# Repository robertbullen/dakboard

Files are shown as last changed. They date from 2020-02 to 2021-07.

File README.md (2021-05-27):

# dakboard

This project starts with a [DIY DAKboard](https://blog.dakboard.com/diy-wall-display/) and customizes it with two features:

- A [Python package](interdaktive/) that interfaces with a PIR motion sensor to programmatically turn the display on and off.
- [Handwritten CSS](css/) for a two-column portrait layout that looks like this:

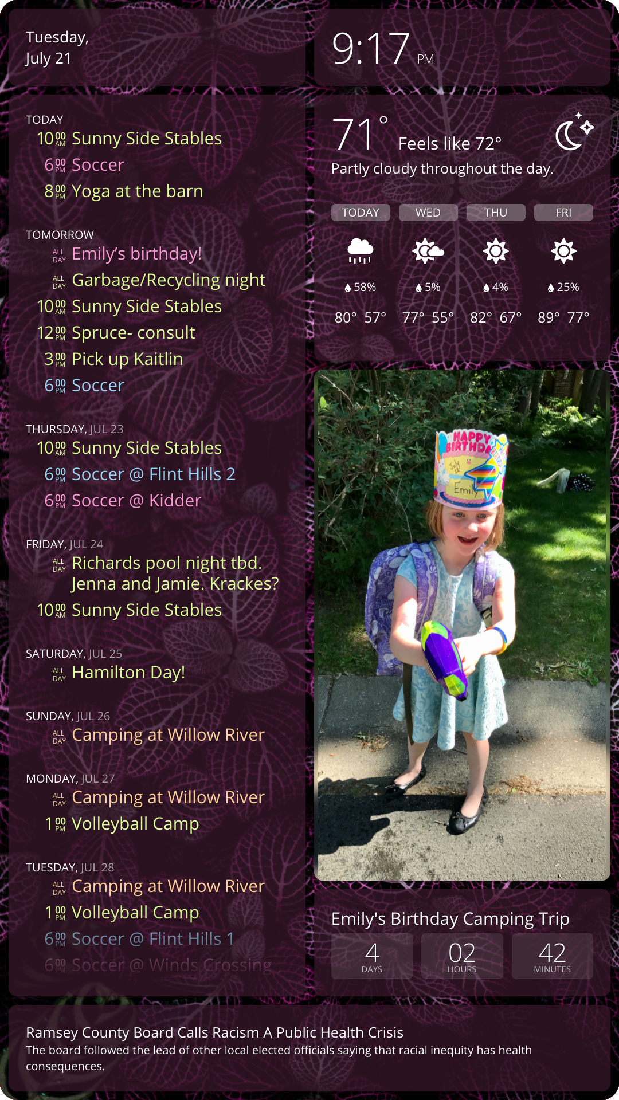
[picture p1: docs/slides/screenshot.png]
    

    _[Background photo](https://unsplash.com/photos/gE1phX0Lbos) by [Hybrid](https://unsplash.com/@artbyhybrid?utm_medium=referral&utm_campaign=photographer-credit&utm_content=creditBadge) on [Unsplash](https://unsplash.com)._

## Presentation

I created an [online presentation](https://robertbullen.github.io/dakboard/) about this project for a talk at work:

- It's a [Reveal.js](https://revealjs.com/#/) project and its source code can be found in this repo's [docs/](docs/) subdirectory. My slides, in particular, are found in [docs/slides/](docs/slides/).
- A viewable instance is hosted by [GitHub Pages](https://pages.github.com/) at <https://robertbullen.github.io/dakboard/>.

## Credits

This project was sponsored in part by my employer, [Constellation](https://constellationmutual.com/). As part of its employee growth and development strategy, Constellation allocates IT staff 12 Personal Hack Days per year to pursue self-guided technology-related interests. I used four of my Personal Hack Days (plus more of my own time) working on this project.

## Software

### Raspberry Pi Configuration

1. Follow the steps found at [DIY Wall Display](https://blog.dakboard.com/diy-wall-display/) until the "Turn the monitor on and off automatically (optional)" section. Rather than control the display on a schedule, as that section explains, this project controls it via a motion sensor.

2. Depending on the display being used, install the HDMI-CEC client. Screenly has a great [article on three ways to turn on/off a monitor](https://www.screenly.io/blog/2017/07/02/how-to-automatically-turn-off-and-on-your-monitor-from-your-raspberry-pi/) programmatically from a Raspberry Pi. That article is two and a half years old at the time of this writing and the installation command is slightly different now:

    ```bash
    sudo apt-get install cec-utils
    ```

    Another great tutorial is [Using HDMI-CEC on a Raspberry Pi](https://pimylifeup.com/raspberrypi-hdmi-cec/).

    With that information in hand, some trial and error lead me to the most effective command for each of the displays that I tested, which I documented in my [presentation](https://robertbullen.github.io/dakboard/#/software-controlling-displays). Your mileage may vary and you may or may not need the CEC client.

3. [_Optional_] Add and configure a USB 3.0-attached SSD drive as the boot drive for a larger swapfile with more reliable I/O.

    > Background:
    >
    > I never needed to configure additional swap space on the Pi 3 that I used for prototyping. But when using the Pi 4 for a matter of hours or days, the system would eventually encounter an out-of-memory scenario that manifested as a Chromium "Aww, Snap!" error. Perhaps I never ran the Pi 3 for long enough to observe the error. Or maybe running the Pi 4 at 1440p (instead of 1080p) is demanding enough to warrant additional memory. In retrospect I wish I would've opted for the 2GB or 4Gb version of the Pi 4 and avoided this issue altogether.
    >
    > Raspbian ships with a preconfigured 100MB swap file at `/var/swap`, which by default resides on the SD card. Simply increasing the size of that swap file prevented the out-of-memory errors. However, there are many warnings online advising against using the SD card for swapping because it isn't made for a lot of random I/O and can eventually become corrupted, taking the OS with it. I can confirm that with my own experiences using cheap SD cards.
    >
    > In an effort to heed those warnings, I first tried using [ZRAM](https://github.com/novaspirit/rpi_zram). This approach lengthened the amount of time between "Aww, Snap!" occurrences, but didn't eliminate them.
    >
    > I eventually settled on using a spare SSD to use as the boot drive, with benefits of faster and more reliable I/O.

    1. Configure the system to boot from an external SSD: <https://www.tomshardware.com/how-to/boot-raspberry-pi-4-usb>.
    2. Increase the swapfile size according to the instructions at <https://nebl.io/neblio-university/enabling-increasing-raspberry-pi-swap/>. In my case, I changed the following lines:

        ```bash
        #CONF_SWAPSIZE=100
        ```

        ```bash
        CONF_SWAPFACTOR=2
        ```

4. Clone this repository to your Raspberry Pi.

    ```bash
    # Substitute your forked repository URL if necessary.
    git clone https://github.com/robertbullen/dakboard.git
    ```

5. Modify `start.sh` script's `start_detector()` function to use desired parameters. For example, you may want to change `--display-type=video-core` to `--display-type=cec` if a TV will be used for the display.

6. Start the Python motion detector on boot by adding these lines to /etc/rc.local:

    ```bash
    # This assumes the user is the default (pi) and that the repository has
    # been cloned to that user's home directory.
    pushd /home/pi/dakboard || exit $?
    sudo ./update.sh || exit $?
    sudo ./start.sh &
    popd
    ```

7. Configure the system to wait for the network at boot:

    Both Chrome and the Python motion detector are started ASAP, and they both require network access to function properly. Do the following to ensure they succeed:

    ```bash
    sudo raspi-config
    ```

    At the time of this writing, the menu choices to make are:

    1. `1 System Options`
    2. `S6 Network at Boot`
    3. `<Yes>`

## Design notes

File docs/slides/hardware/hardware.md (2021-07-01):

<!-- .slide: id="hardware-hardware" -->
# Hardware

===
<!-- .slide: class="columns layout" id="hardware-prototype" -->
## Prototype

- Column

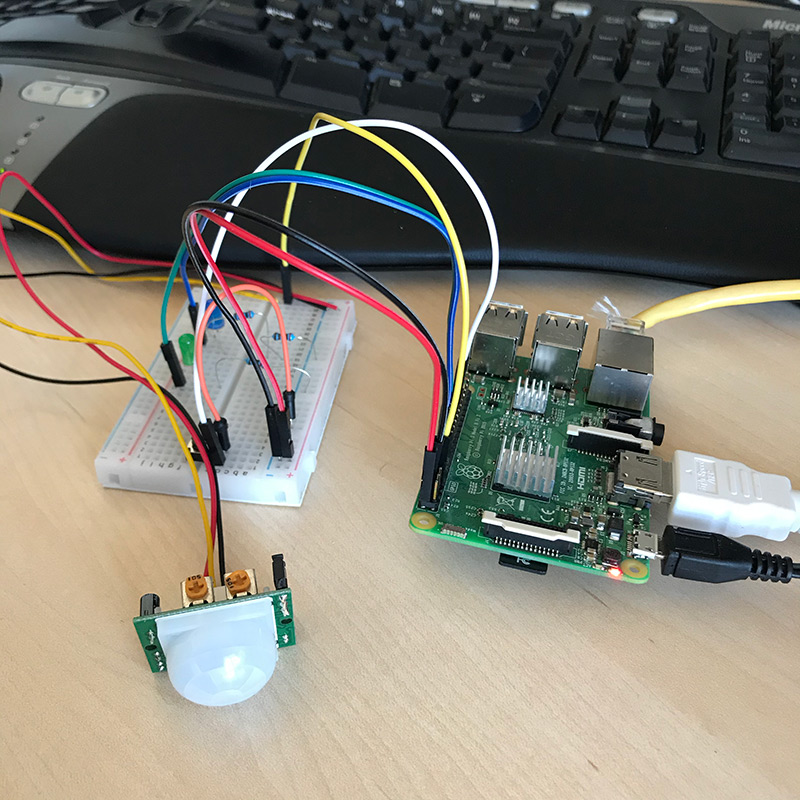
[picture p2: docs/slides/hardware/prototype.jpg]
Prototype Photo
    

- Column

    - Experimentation started with hardware that I mostly already owned...

===
<!-- .slide: class="columns layout" -->
### [Samsung 32" Class M5300 Full HD TV](https://www.samsung.com/us/televisions-home-theater/tvs/full-hd-tvs/32--class-m5300-full-hd-tv-un32m5300afxza/)

- Column

    - Recently retired
    - Full HD (1920×1080) resolution
    - \$0

- Column

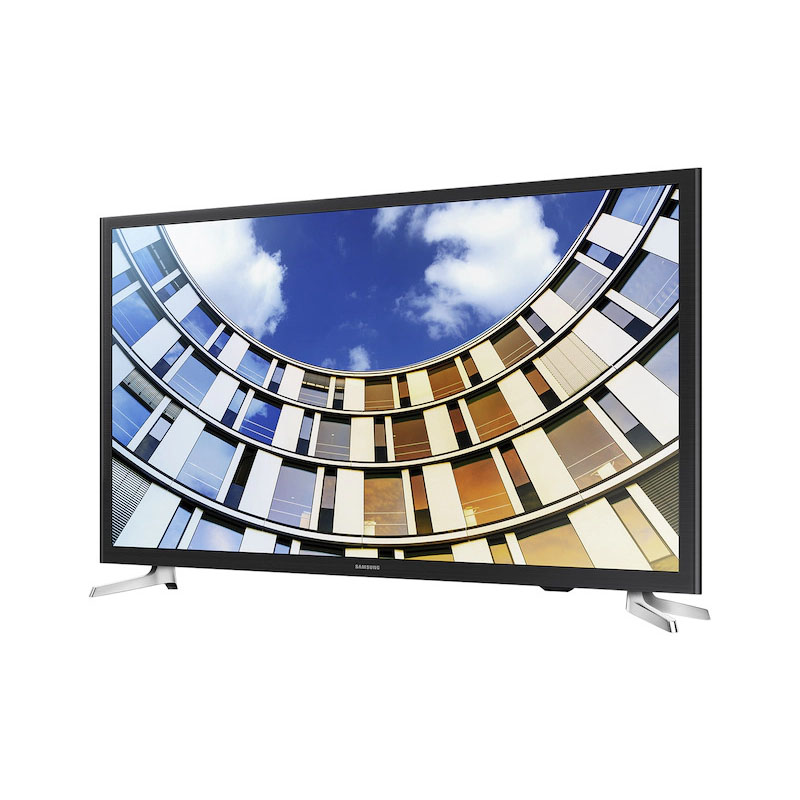
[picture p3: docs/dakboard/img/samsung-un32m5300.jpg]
Samsung 32" Class M5300 Full HD TV
    

===
<!-- .slide: class="columns layout" -->
### [Raspberry Pi 3 Model B](https://www.raspberrypi.org/products/raspberry-pi-3-model-b/)

- Column

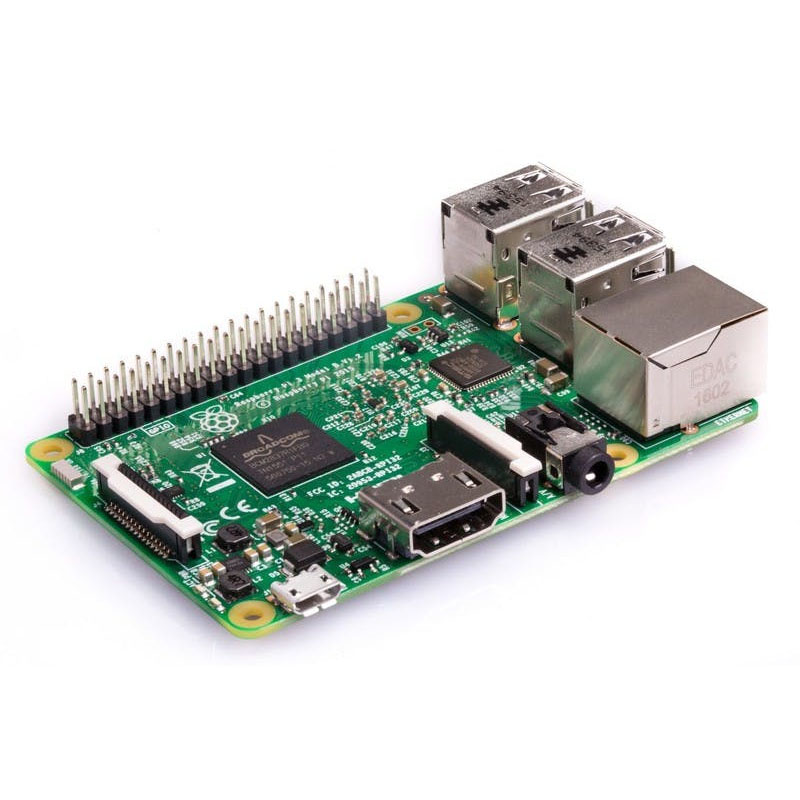
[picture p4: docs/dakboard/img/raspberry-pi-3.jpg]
Raspberry Pi 3 Model B
    

- Column

    - Received as a prize at a work function years ago
    - Came with a power supply and heat sinks
    - Sufficient to drive the Full HD TV
    - \$0

===
<!-- .slide: class="columns layout" -->
### [Adafruit PIR Sensor](https://www.adafruit.com/product/189)

- Column

    - Senses motion from the IR emitted by our bodies up to 7 meters away within a 120-degree cone
    - Runs on 5V–12V power and the Pi provides 5V
    - Comes with a 1-foot cable/socket
    - Configurable with different triggering signals, timings, and sensitivities
    - There are cheaper alternatives, but their reviews are poor
    - \$11

- Column

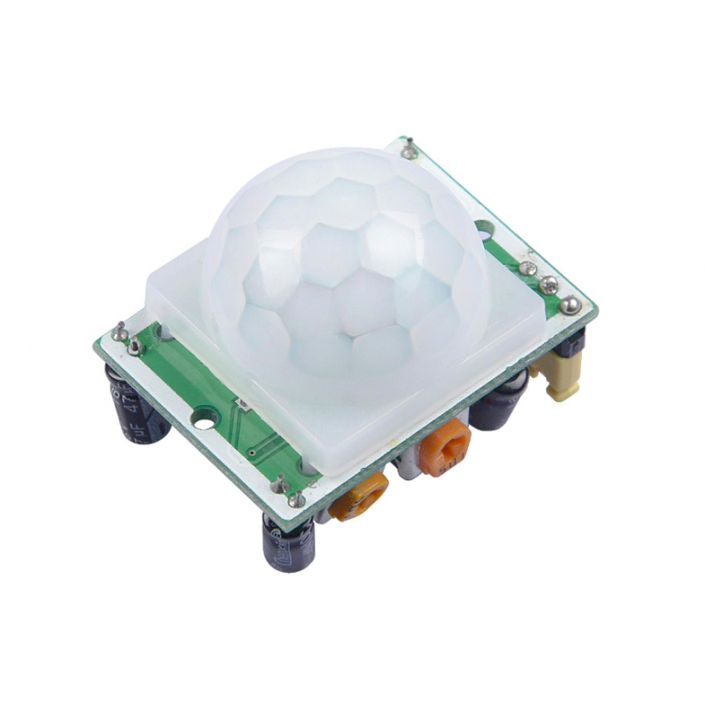
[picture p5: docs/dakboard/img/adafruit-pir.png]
Adafruit PIR Sensor
    

===
<!-- .slide: class="columns layout" -->
### [Smraza Basic Starter Kit with Breadboard](https://www.amazon.com/gp/product/B01HRR7EBG/ref=ppx_yo_dt_b_asin_title_o09_s00?ie=UTF8&psc=1)

- Column

    Smraza Basic Starter Kit with Breadboard

- Column

    - Includes the following necessities and more:
        - Breadboard
        - Power supply
        - LEDs
        - Resistors
        - Push buttons
        - Patch wires
    - \$13

===
### Fritzing Wiring Diagram

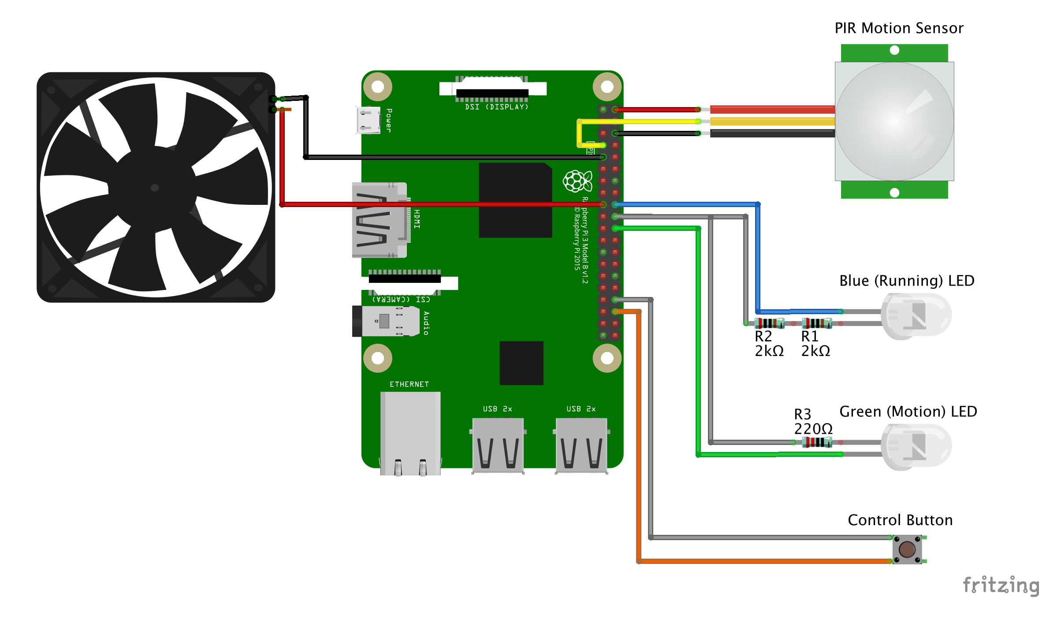
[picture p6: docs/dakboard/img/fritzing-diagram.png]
Fritzing Diagram
 <!-- .element: style="max-height: 900px;" -->

===
### Pinout.xyz Consolidates Raspberry Pi GPIO Info

<iframe class="stretch" data-src="https://pinout.xyz/"></iframe>

===
### Prototype Costs

| Part | Cost |
| --- | ---: |
| [Smraza Basic Starter Kit with Breadboard](https://www.amazon.com/gp/product/B01HRR7EBG/ref=ppx_yo_dt_b_asin_title_o09_s00?ie=UTF8&psc=1) | \$13 |
| [Adafruit PIR Sensor](https://www.adafruit.com/product/189) | \$11 |
| [Samsung 32" Class M5300 Full HD TV](https://www.samsung.com/us/televisions-home-theater/tvs/full-hd-tvs/32--class-m5300-full-hd-tv-un32m5300afxza/) |  \$0 |
| [Raspberry Pi 3 Model B](https://www.raspberrypi.org/products/raspberry-pi-3-model-b/) |  \$0 |
| | \$24 |

===
<!-- .slide: class="columns layout" id="hardware-final-design" -->
## Final Design

- Column

    - The prototype proved out the concept, so it was time to design a permanent solution
    - The following hardware upgrades were used for the final design

- Column

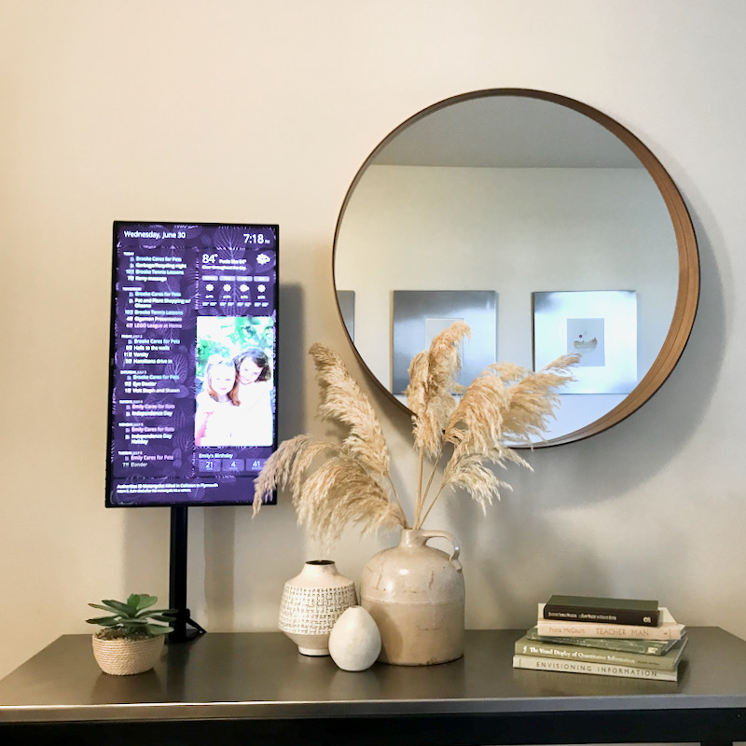
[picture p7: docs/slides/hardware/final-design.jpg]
Final Design
    

===
<!-- .slide: class="columns layout" -->
### [Dell UltraSharp 25" QHD Monitor (U2518D)](https://www.dell.com/ng/business/p/dell-u2518d-monitor/pd)

- Column

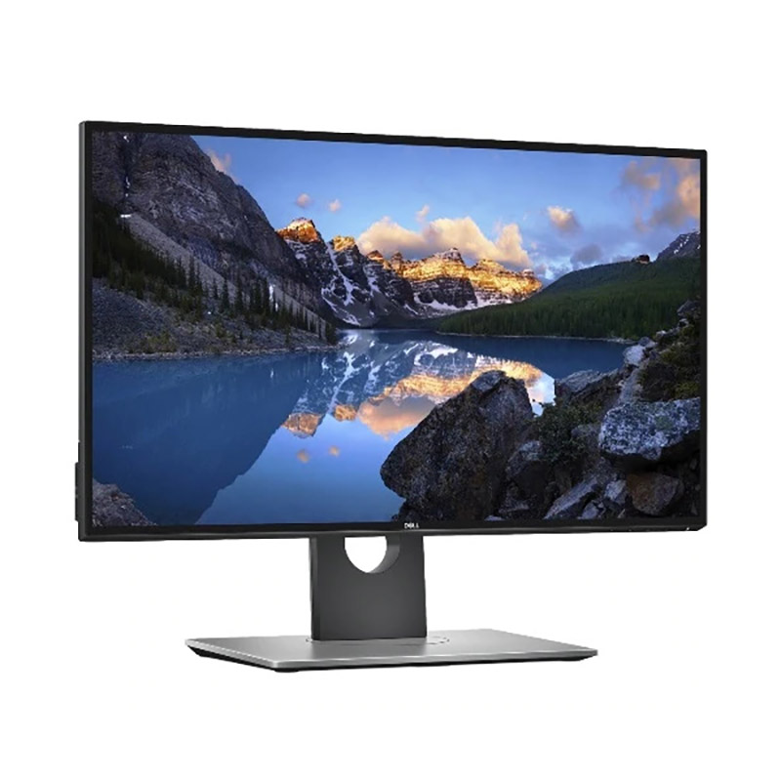
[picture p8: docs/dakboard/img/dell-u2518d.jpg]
Dell UltraSharp 25" QHD Monitor (U2518D)
    

- Column

    - The 32" TV was too large and too pixelated for the intended location and viewing distance
    - This monitor has a 25" screen, which is about the right size for this installation
    - Employs an IPS panel with good viewing angles, even in portrait mode
    - Projects a QHD resolution (2560×1440) yielding 117ppi for crisper text and sharper images
    - Purchased used from a coworker
    - \$125

===
<!-- .slide: class="columns layout" -->
### [WALI Monitor Stand](https://www.amazon.com/gp/product/B07S1V2VN7/ref=ppx_yo_dt_b_asin_title_o00_s00?ie=UTF8&psc=1)

- Column

    - A monitor stand was chosen over wall mounting
    - Two other WALI stands were already present in my home office
        - Affordable, functional, and parts are interchangeable
    - \$38

- Column

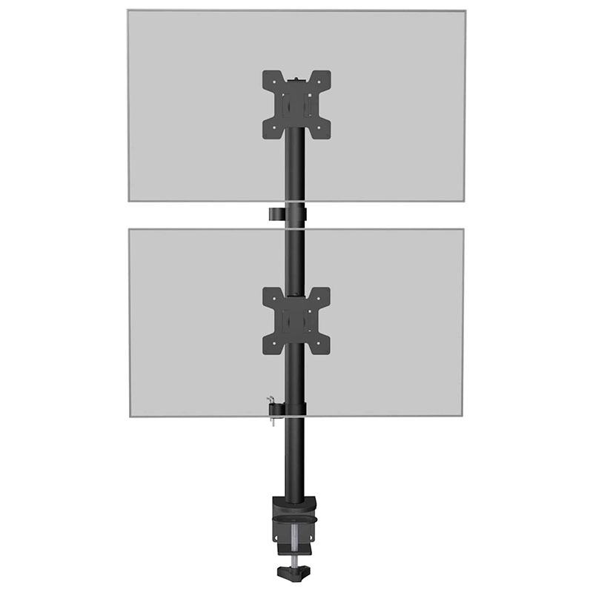
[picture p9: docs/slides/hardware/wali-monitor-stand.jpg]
WALI Monitor Stand
    

===
<!-- .slide: class="columns layout" -->
### [Raspberry Pi 4 Model B with 1GB RAM](https://www.raspberrypi.org/products/raspberry-pi-4-model-b/)

- Column

    Raspberry Pi 4 Model B with 1GB RAM

- Column

    - Pi 4 is the only model capable of going above Full HD, up to 4K (3840×2160)
    - Available with 1GB, 2GB, 4GB or 8GB of RAM
    - Also purchased a power supply and inexpensive 16GB microSD
    - \$45

    ***

    - Hindsight:
        - Consider purchasing a Pi with more RAM to avoid needing a separate swap drive
        - Don't use inexpensive microSD cards because they're too unreliable to be an OS drive

===
<!-- .slide: class="columns layout" -->
### [Smraza Case for Raspberry Pi 4 B](https://www.amazon.com/gp/product/B07VDCT57F/ref=ppx_yo_dt_b_asin_title_o04_s01?ie=UTF8&psc=1)

- Column

    - Protects and cools the Pi 4, which can run hot
    - \$10

- Column

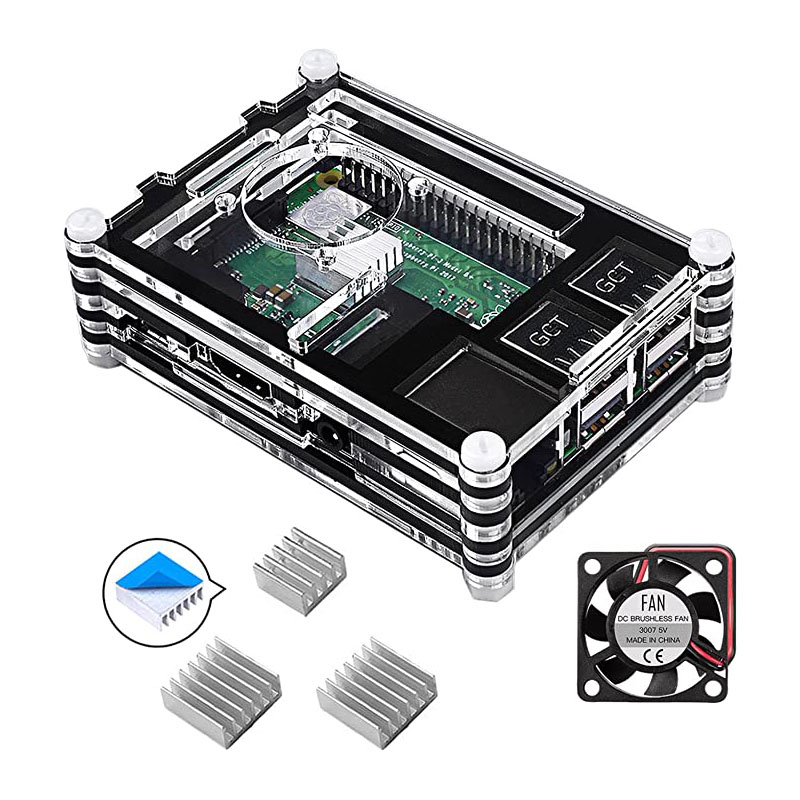
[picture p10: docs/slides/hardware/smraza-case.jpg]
Smraza Case for Raspberry Pi 4 B
    

===
<!-- .slide: class="columns layout" -->
### [Samsung 120GB 2.5-inch SSD 840](https://www.samsung.com/uk/support/model/MZ-7TD120BW/)

- Column

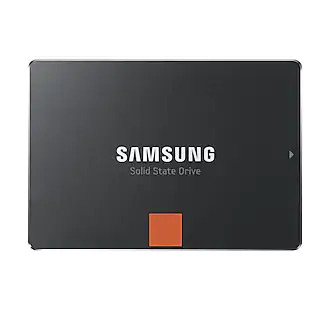
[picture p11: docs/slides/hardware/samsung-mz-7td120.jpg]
Samsung 120GB 2.5-inch SSD 840
    

- Column

    - Boosts performance and reliability
    - Extracted from a retired computer
    - \$0

===
<!-- .slide: class="columns layout" -->
### [SKL Tech USB 3.0/SATA III Hard Drive Adapter Cable](https://www.amazon.com/Drive-Adapter-Cable-Support-Black/dp/B07S9CKV7X)

- Column

    - Necessary to attach the SSD
    - James A Chambers has a thorough [Pi 4 Bootloader guide](https://jamesachambers.com/new-raspberry-pi-4-bootloader-usb-network-boot-guide/) backed by benchmark data and it recommends a similar but different product for max performance and reliability
    - This one is cheaper and still does the job
    - \$8

- Column

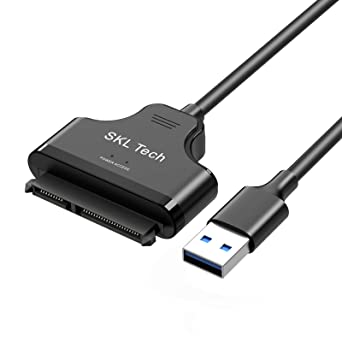
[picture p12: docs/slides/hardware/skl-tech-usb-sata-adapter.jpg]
SKL Tech USB 3.0/SATA III Hard Drive Adapter Cable
    

===
### Final Design Costs

| Part |  Cost |
| --- | ----: |
| [Dell UltraSharp 25" QHD Monitor (U2518D)](https://www.dell.com/en-us/work/shop/dell-ultrasharp-25-monitor-u2518d/apd/210-amll/monitors-monitor-accessories) | \$125 |
| [Raspberry Pi 4 Model B with 1GB RAM](https://www.raspberrypi.org/products/raspberry-pi-4-model-b/) and accessories |  \$45 |
| [WALI Monitor Stand](https://www.amazon.com/gp/product/B07S1V2VN7/ref=ppx_yo_dt_b_asin_title_o00_s00?ie=UTF8&psc=1) |  \$38 |
| [Adafruit PIR Sensor](https://www.adafruit.com/product/189) |  \$11 |
| [Smraza Case for Rasberry Pi 4 B](https://www.amazon.com/gp/product/B07VDCT57F/ref=ppx_yo_dt_b_asin_title_o04_s01?ie=UTF8&psc=1) |  \$10 |
| [SKL Tech USB 3.0/SATA III Hard Drive Adapter Cable](https://www.amazon.com/Drive-Adapter-Cable-Support-Black/dp/B07S9CKV7X) | $8 |
| [Samsung 120GB 2.5-inch SSD 840](https://www.samsung.com/uk/support/model/MZ-7TD120BW/) | \$0 |
| | \$237 |

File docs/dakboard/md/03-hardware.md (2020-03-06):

<!-- .slide: id="hardware-hardware" -->

# Hardware

===

<!-- .slide: id="hardware-prototype" -->

## Prototype

Experimentation started with the following hardware that I mostly already owned

===

<!-- .slide: class="columns layout" -->

### [Samsung 32" Class M5300 Full HD TV](https://www.samsung.com/us/televisions-home-theater/tvs/full-hd-tvs/32--class-m5300-full-hd-tv-un32m5300afxza/)

- Column

    Samsung 32" Class M5300 Full HD TV

- Column

    - After moving homes we no longer had an obvious spot for this TV, so it was available for experimentation
    - Being a TV, it is more effective to suspend and awake it using the HDMI-CEC protocol
    - Only 70ppi
    - \$0

===

<!-- .slide: class="columns layout" -->

### [Raspberry Pi 3 Model B](https://www.raspberrypi.org/products/raspberry-pi-3-model-b/)

- Column

    Raspberry Pi 3 Model B

- Column

    - I received this as a prize at a work function years ago
    - Can drive resolutions up to Full HD (1920×1080)
    - \$0

===

<!-- .slide: class="image left layout" -->

### [Adafruit PIR Sensor](https://www.adafruit.com/product/189)

Adafruit PIR Sensor

- Passive Infrared sensor detects motion
- A nicely detailed [guide](https://cdn-learn.adafruit.com/downloads/pdf/pir-passive-infrared-proximity-motion-sensor.pdf) is available
- \$11 from Amazon because Adafruit was out of stock!
- There are cheaper alternatives, but product reviews were poor

===

<!-- .slide: class="image left layout" -->

### [Smraza Basic Starter Kit with Breadboard](https://www.amazon.com/gp/product/B01HRR7EBG/ref=ppx_yo_dt_b_asin_title_o09_s00?ie=UTF8&psc=1)

Smraza Basic Starter Kit with Breadboard

- I needed a breadboard, power supply, LEDs, resistors, push buttons, and patch wires to familiarize myself with the PIR sensor and programming the Pi's GPIO pins. This kit has all that and more.
- I feel like owning this kit gives me some hacker cred!
- \$13

===

### Wiring

Fritzing Diagram

===

<!-- .slide: id="hardware-final-design" -->

## Final Design

- The prototype hardware would've been sufficient at longer viewing distances
- The 32" is too large for the intended location
- Closer up Full HD (1080×1920) display is too pixelated
- The following hardware was used for the final design

===

<!-- .slide: class="image left layout" -->

### [Dell UltraSharp 25" QHD Monitor (U2518D)](https://www.dell.com/en-us/work/shop/dell-ultrasharp-25-monitor-u2518d/apd/210-amll/monitors-monitor-accessories)

Dell UltraSharp 25" QHD Monitor (U2518D)

- Has a 25" screen, which is about the right size for this application
- Employs an IPS panel with good viewing angles, even in portrait mode
- Projects a QHD resolution (2560×1440) yielding 117ppi for crisper text and sharper images
- \$125 used from a coworker

===

<!-- .slide: class="image left layout" -->

### [Raspberry Pi 4 Model B with 1GB RAM](https://www.raspberrypi.org/products/raspberry-pi-4-model-b/)

Raspberry Pi 4 Model B with 1GB RAM

- Pi 4 is the only model capable of going above Full HD (1920×1080)
- \$45 included a power supply and inexpensive 16GB microSD
- Hindsight: purchase a 2GB or 4GB model to avoid the next slide

===

<!-- .slide: class="image left layout" -->

### 2GB USB Thumb Drive

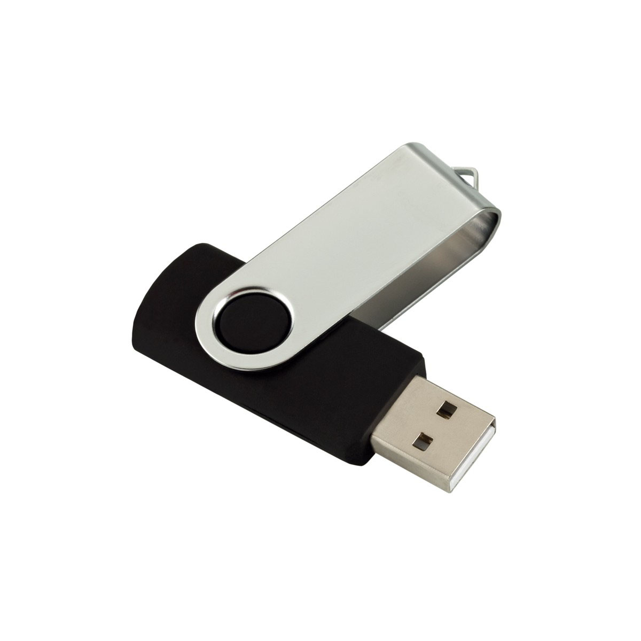
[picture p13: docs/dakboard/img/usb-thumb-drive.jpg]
USB Thumb Drive


- Needed for swap space
- \$0 (already owned)
- Hindsight: Avoid this by purchasing a 2GB or 4GB Pi 4

===

<!-- .slide: id="hardware-costs" -->

## Costs

===

### Prototype Costs

| Part | Cost |
| --- | ---: |
| [Samsung 32" Class M5300 Full HD TV](https://www.samsung.com/us/televisions-home-theater/tvs/full-hd-tvs/32--class-m5300-full-hd-tv-un32m5300afxza/) |  \$0 |
| [Raspberry Pi 3 Model B](https://www.raspberrypi.org/products/raspberry-pi-3-model-b/) |  \$0 |
| [Adafruit PIR Sensor](https://www.adafruit.com/product/189) | \$11 |
| [Smraza Basic Starter Kit with Breadboard](https://www.amazon.com/gp/product/B01HRR7EBG/ref=ppx_yo_dt_b_asin_title_o09_s00?ie=UTF8&psc=1) | \$13 |
| | \$24 |

===

### Final Design Costs

| Part |  Cost |
| --- | ----: |
| [Dell UltraSharp 25" QHD Monitor (U2518D)](https://www.dell.com/en-us/work/shop/dell-ultrasharp-25-monitor-u2518d/apd/210-amll/monitors-monitor-accessories) | \$125 |
| [Raspberry Pi 4 Model B with 1GB RAM](https://www.raspberrypi.org/products/raspberry-pi-4-model-b/) and accessories |  \$45 |
| [Adafruit PIR Sensor](https://www.adafruit.com/product/189) |  \$11 |
| 2GB USB Thumb Drive | \$0 |
| | \$181 |

<!-- | [Smraza Case for Rasberry Pi 4 B](https://www.amazon.com/gp/product/B07VDCT57F/ref=ppx_yo_dt_b_asin_title_o04_s01?ie=UTF8&psc=1)                     | \$10 | -->

===

### Costs Compared to Off-the-Shelf DAKboard

TODO: Cost comparison

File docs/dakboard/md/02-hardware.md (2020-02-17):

# Hardware

===

## Final Design

TODO: The hardware used in this final design.

===

<!-- .slide: class="hardware-product" -->

### [Dell UltraSharp 25" QHD Monitor (U2518D)](https://www.dell.com/en-us/work/shop/dell-ultrasharp-25-monitor-u2518d/apd/210-amll/monitors-monitor-accessories)

Dell UltraSharp 25" QHD Monitor (U2518D) <!-- .element class="product-image" -->

- Has a 25" screen, which is about the right size for this application
- Employs an IPS panel with good viewing angles, even in portrait mode
- Projects a QHD resolution (2560×1440) yielding 117ppi for crisper text and sharper images
- \$125 used from a coworker

===

<!-- .slide: class="hardware-product" -->

### [Raspberry Pi 4 Model B with 1GB RAM](https://www.raspberrypi.org/products/raspberry-pi-4-model-b/)

Raspberry Pi 4 Model B with 1GB RAM

- Pi 4 is the only model capable of going above Full HD (1920×1080)
- \$45 included a power supply and inexpensive 16GB microSD
- Hindsight: purchase a 2GB or 4GB model to avoid the next slide

===

<!-- .slide: class="hardware-product" -->

### 2GB USB Thumb Drive

USB Thumb Drive

- Needed for swap space
- \$0 (already owned)
- Hindsight: Avoid this by purchasing a 2GB or 4GB Pi 4

===

<!-- .slide: class="hardware-product" -->

### [Adafruit PIR Sensor](https://www.adafruit.com/product/189)

Adafruit PIR Sensor

- Passive Infrared sensor detects motion
- A nicely detailed [guide](https://cdn-learn.adafruit.com/downloads/pdf/pir-passive-infrared-proximity-motion-sensor.pdf) is available
- \$11 from Amazon because Adafruit was out of stock!
- There are cheaper alternatives, but product reviews were poor

===

## Prototype

Development was conducted on hardware that I already owned before I invested in the equipment above. This hardware would've been sufficient at a viewing distance farther away from the screen than I was planning. Close up the 32" Full HD (1080×1920) display is too large and pixelated.

===

<!-- .slide: class="hardware-product" -->

### [Samsung 32" Class M5300 Full HD TV](https://www.samsung.com/us/televisions-home-theater/tvs/full-hd-tvs/32--class-m5300-full-hd-tv-un32m5300afxza/)

Samsung 32" Class M5300 Full HD TV

- After moving homes we no longer had an obvious spot for this TV, so it was available for experimentation
- Being a TV, it is more effective to suspend and awake it using the HDMI-CEC protocol
- Only 70ppi
- \$0

===

<!-- .slide: class="hardware-product" -->

### [Raspberry Pi 3 Model B](https://www.raspberrypi.org/products/raspberry-pi-3-model-b/)

Raspberry Pi 3 Model B

- I received this as a prize at a work function years ago
- Can drive resolutions up to Full HD (1920×1080)
- \$0

===

<!-- .slide: class="hardware-product" -->

### [Smraza Basic Starter Kit with Breadboard](https://www.amazon.com/gp/product/B01HRR7EBG/ref=ppx_yo_dt_b_asin_title_o09_s00?ie=UTF8&psc=1)

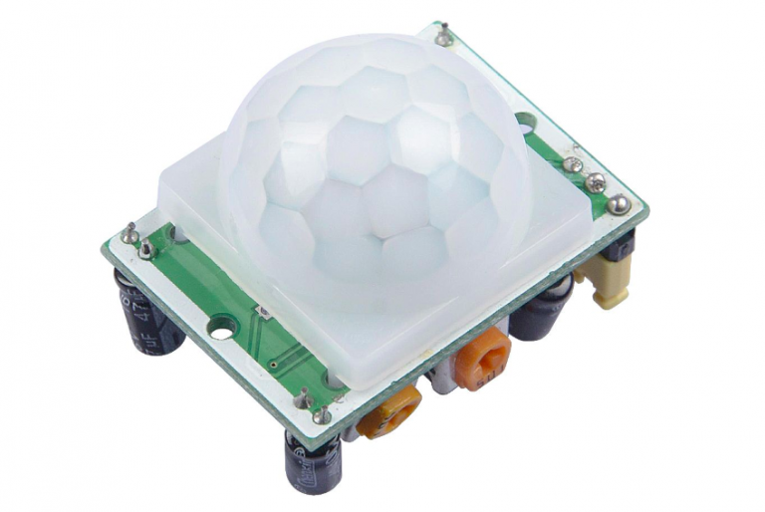
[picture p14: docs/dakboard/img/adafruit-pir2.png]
Adafruit PIR Sensor


- I needed a breadboard, power supply, LEDs, resistors, push buttons, and patch wires to familiarize myself with the PIR sensor and programming the Pi's GPIO pins. This kit has all that and more.
- I feel like owning this kit gives me some hacker cred!
- \$13

===

## Costs

===

### Prototype Design Costs

| Part | Cost |
| --- | ---: |
| [Samsung 32" Class M5300 Full HD TV](https://www.samsung.com/us/televisions-home-theater/tvs/full-hd-tvs/32--class-m5300-full-hd-tv-un32m5300afxza/) |  \$0 |
| [Raspberry Pi 3 Model B](https://www.raspberrypi.org/products/raspberry-pi-3-model-b/) |  \$0 |
| [Smraza Basic Starter Kit with Breadboard](https://www.amazon.com/gp/product/B01HRR7EBG/ref=ppx_yo_dt_b_asin_title_o09_s00?ie=UTF8&psc=1) | \$13 |
| [Smraza Case for Rasberry Pi 4 B](https://www.amazon.com/gp/product/B07VDCT57F/ref=ppx_yo_dt_b_asin_title_o04_s01?ie=UTF8&psc=1) | \$10 |
| | \$23 |

===

### Final Design Costs

| Part |  Cost |
| --- | ----: |
| [Dell UltraSharp 25" QHD Monitor (U2518D)](https://www.dell.com/en-us/work/shop/dell-ultrasharp-25-monitor-u2518d/apd/210-amll/monitors-monitor-accessories) | \$125 |
| [Raspberry Pi 4 Model B with 1GB RAM](https://www.raspberrypi.org/products/raspberry-pi-4-model-b/) and accessories |  \$45 |
| [Adafruit PIR Sensor](https://www.adafruit.com/product/189) |  \$11 |
| 2GB USB Thumb Drive | \$0 |
| | \$181 |

===

### Costs Compared to Offical DAKboard

TODO: Cost comparison

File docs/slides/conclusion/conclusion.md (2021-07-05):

<!-- .slide: id="conclusion-conclusion" -->
# Conclusion

===
<!-- .slide: id="conclusion-comparisons" -->
## Comparing DAKboards

<style>
    #conclusion-comparisons table {
        font-size: 67%;
    }
</style>

| | Off-the-Shelf | Custom-Built | Notes |
| --- | --- | --- | --- |
| Cost | 🟠 \$400 | 🟢 $261 | Prototype + final |
| Pi Model | 🟠 Pi 3 | 🟢 Pi 4 | Faster CPU; supports 4K displays |
| OS Disk | 🟠 SD Card | 🟢 SSD | Speedier, more reliable I/O |
| Performance & Reliability | 🟠 Fair | 🟢 Great | No crashing or stuttering |
| Screen | 🟠 24" / 1920×1080 / 92ppi | 🟢 25" / 2560×1440 / 117ppi | Larger, sharper |
| Information Density | 🟠 Low | 🟢 High | More readable font; custom design |
| Design Scalability | 🟠 Fair | 🟢 Near Pixel-Perfect | CSS with relative units and positioning |
| Power Savings Options | 🟠 Manual | 🟢 Auto | Motion-aware; off-hours; push-button-override |
| Diagnostics & Insights | 🟠 None | 🟢 Website | State machine diagram and log |

===
<!-- .slide: id="conclusion-benefits" -->
# Benefits & ROI

| | Off-the-Shelf | Custom-Built | Notes |
| --- | --- | --- | --- |
| Wife Acceptance Factor | 🟠 Good | 🟢 Better | Appreciates uniqueness and functionality |
| Pride & Satisfaction | 🟠 Some | 🟢 More | Regularly reminded |
| Learnings | 🟠 Little | 🟢 Tons | See next slide |
| Career-Benefitting | 🟠 None | 🟢 Some | Exposure to new tech; presenting |

===
<!-- .slide: class="columns layout" id="conclusion-learnings" style="font-size: smaller" -->
## Learnings

- Column

    - Hardware
        - Raspberry Pi models, capabilities and limitation, pin features, disk options for performance and reliability
        - HDMI-CEC protocol and commands
        - PIR sensors and basic electronics parts
        - Fritzing for documenting/designing circuits
    - Design
        - Font terminology and features
        - Image color analysis and cohesive color palette selection tools
        - CSS variables and calculations
    - Presenting
        - Reveal.js and creating plugins for it
        - Programmatic webcam access
        - GitHub Pages for hosting this presentation

- Column

    - Python
        - Creating packages and managing dependencies
        - GPIO pin programming paradigms
        - Static typing
        - Multiple inheritance via `mixins`
        - Immutable named tuples via `dataclasses`
        - Custom iterable instances
        - Dynamic module loading
        - File watching, REST server, WebSockets, incompatible threading models
        - Finite state machines

===
<!-- .slide: id="conclusion-plans-and-ideas" -->
## Future Plans and Ideas

- Try pulsing instead of blinking LEDs using PWM via hardware pins or software emulation
- Create different screen layouts with different goals and content and loop them
- Experiment with CSS Grid for arranging dashboard tiles (as opposed to absolute positioning)
- Define systemd template unit files for startup/shutdown

===
<!-- .slide: class="columns layout" id="conclusion-links" -->
## Links

- Column

    This Presentation

    [This Presentation](https://robertbullen.github.io/dakboard)

- Column

    GitHub Repo

    [GitHub Repo](https://github.com/robertbullen/dakboard)

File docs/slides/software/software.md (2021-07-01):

<!-- .slide: id="software-software" -->
# Software

===
<!-- .slide: class="columns layout" id="software-controlling-displays" -->
## Controlling Displays

<style>
    #software-controlling-displays table {
        font-size: smaller;
    }
    #software-controlling-displays table td {
        vertical-align: middle;
    }
    #software-controlling-displays table td:nth-of-type(2) {
        white-space: nowrap;
    }
    #software-controlling-displays table td:nth-of-type(3) {
        font-size: larger;
        text-align: center;
    }
</style>

| Display | Command | Results | Notes |
| --- | --- | --- | --- |
| Dell U2518D | `cec-client` | 👎 | The Dell doesn't respond to CEC commands, which is to be expected because it's a computer monitor and not a home theater component. |
| Dell U2518D | `vcgencmd` | 👍 | The Dell goes to sleep 15–20 seconds after the HDMI signal turns off, and wakes back up in about 5 seconds when the signal returns. |
| Samsung UN32M5300 | `cec-client` | 👍 | The Samsung responds nicely to CEC commands telling the TV to enter standby mode or active mode. |
| Samsung UN32M5300 | `vcgencmd` | 👎 | The Samsung stays on for several minutes after the HDMI signal turns off, presenting a "No Signal" screen, which is undesirable. It also doesn't awake when the HDMI signal turns back on. |

===
<!-- .slide: id="software-samsung-tv-features" -->
## Samsung TV Features

<style>
    #software-samsung-tv-features img {
        height: 600px;
    }
</style>

<div class="figures equisized">
    <figure>
        <h4>No Signal Screen</h4>
        <p>
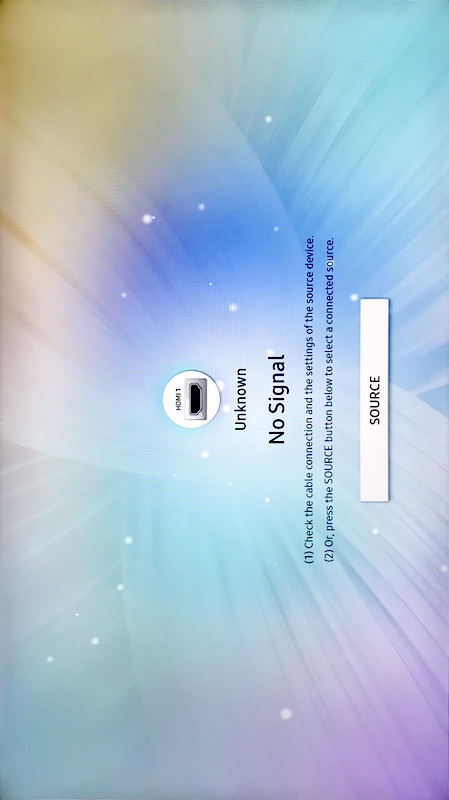
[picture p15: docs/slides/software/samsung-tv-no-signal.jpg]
Samsung TV No Signal
            
        </p>
        <figcaption>Displays for several minutes after turning off HDMI signal&mdash;workaround is to use CEC commands</figcaption>
    </figure>
    <figure>
        <h4>Input Banner</h4>
        <p>
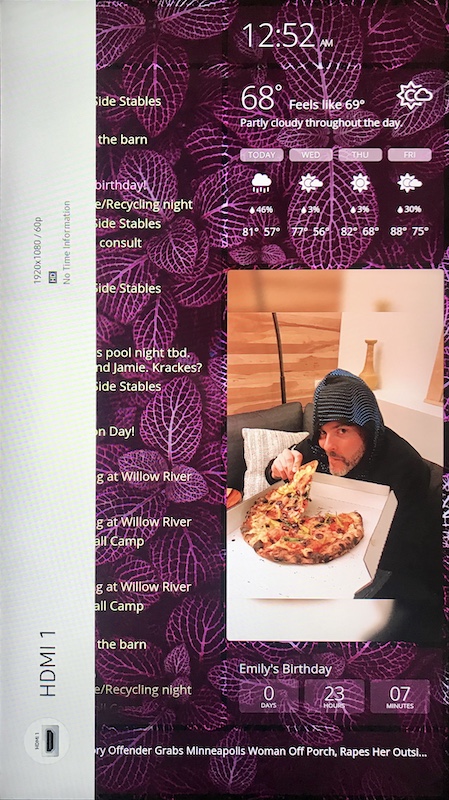
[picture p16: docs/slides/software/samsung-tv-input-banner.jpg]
Samsung TV Input Banner
            
        </p>
        <figcaption>Overlays for several seconds after awakening&mdash;no workaround</figcaption>
    </figure>
</div>

===
<!-- .slide: id="software-python-packages" -->
## Python Packages

===
### `argparse` for CLI Arguments

```plaintext
usage: python3 -m interdaktive [-h] --motion-sensor-pin MOTION_SENSOR_PIN
                               [--control-button-pin CONTROL_BUTTON_PIN]
                               [--display-type {cec,mock,video-core}]
                               [--motion-led-pin MOTION_LED_PIN]
                               [--running-led-pin RUNNING_LED_PIN]
                               [--timer-seconds TIMER_SECONDS]
                               [--waking-hours-begin WAKING_HOURS_BEGIN]
                               [--waking-hours-end WAKING_HOURS_END]
                               [--log-file-path LOG_FILE_PATH]
                               [--state-diagram-file-path STATE_DIAGRAM_FILE_PATH]

optional arguments:
  -h, --help            show this help message and exit

hardware arguments:
  GPIO pins must be specified in gpiozero pin numbering format, which is
  described at https://gpiozero.readthedocs.io/en/stable/recipes.html#pin-
  numbering.

  --motion-sensor-pin MOTION_SENSOR_PIN
                        The GPIO pin to which the motion sensor is attached.
                        Detecting motion is this package's raison d'être, and
                        no reasonable default can be assumed, so this is the
                        one and only required argument.
  --control-button-pin CONTROL_BUTTON_PIN
                        The GPIO pin to which an optional control button is
                        attached. Pressing the button will forcibly toggle the
                        display, even outside of waking hours. Holding the
                        button for 5 seconds will shutdown the system.
  --display-type {cec,mock,video-core}
                        The type of display that is connected, which
                        determines how it is put to sleep and awakened. A
                        'video-core' display simply responds to the HDMI
                        signal turning off and on; e.g. a computer monitor. A
                        'cec' display responds to HDMI-CEC commands; e.g. a
                        TV. A 'mock' display is useful for testing and simply
                        outputs its state changes to the console.
  --motion-led-pin MOTION_LED_PIN
                        The GPIO pin to which an optional motion indicator LED
                        is attached.
  --running-led-pin RUNNING_LED_PIN
                        The GPIO pin to which an optional running indicator
                        LED is attached.

timing arguments:
  --timer-seconds TIMER_SECONDS
                        The length of time (in seconds) for the display to
                        stay awake/asleep after detecting motion or the
                        control button is pressed. Also the length of time
                        that the display will remain in its forcibly toggled
                        state after pressing the control button.
  --waking-hours-begin WAKING_HOURS_BEGIN
                        The beginning of the daily period (in 24-hour clock
                        format; e.g. 06:00) when detecting motion will wake
                        the display.
  --waking-hours-end WAKING_HOURS_END
                        The end of the daily period (in 24-hour clock format;
                        e.g. 22:00) when detecting motion will wake the
                        display.

output arguments:
  --log-file-path LOG_FILE_PATH
                        The file path to which logging output will be written.
  --state-diagram-file-path STATE_DIAGRAM_FILE_PATH
                        The file path to which state diagram images will be
                        written.
```
<!-- .element: class="stretch" -->

===
<!-- .slide: class="columns layout" -->
### `gpiozero` for Controlling GPIO Pins

- Column

    Typical examples using `RPi.GPIO`:

    <pre><code class="language-python" data-line-numbers data-trim>
    import RPi.GPIO as GPIO

    GPIO.setmode(GPIO.BOARD)
    GPIO.setwarnings(False)

    button_pin = 3
    GPIO.setup(button_pin, GPIO.IN, GPIO.PUD_UP)

    led_pin = 5
    GPIO.setup(led_pin, GPIO.OUT)

    while True:
        # Wait for button to be pressed, then turn on the LED.
        GPIO.wait_for_edge(button_pin, GPIO.FALLING)
        GPIO.output(led_pin, GPIO.HIGH)

        # Wait for button to be released, then turn off the LED.
        GPIO.wait_for_edge(button_pin, GPIO.RISING)
        GPIO.output(led_pin, GPIO.LOW)

        # Some loop termination condition...

    GPIO.cleanup()
    </code></pre>

- Column

    Higher level abstractions with `gpiozero`:

    <pre><code class="language-python" data-line-numbers data-trim>
    from gpiozero import LED, Button
  
    button = Button('BOARD3')
    led = LED('BOARD5')

    button.when_pressed = led.on
    button.when_released = led.off
    </code></pre>

    - Reads more succinctly
    - Provides mocking for unit testing
    - Takes care of threading/non-blocking
    - Takes care of cleanup

===
<h3>Finite State Machines</h3>
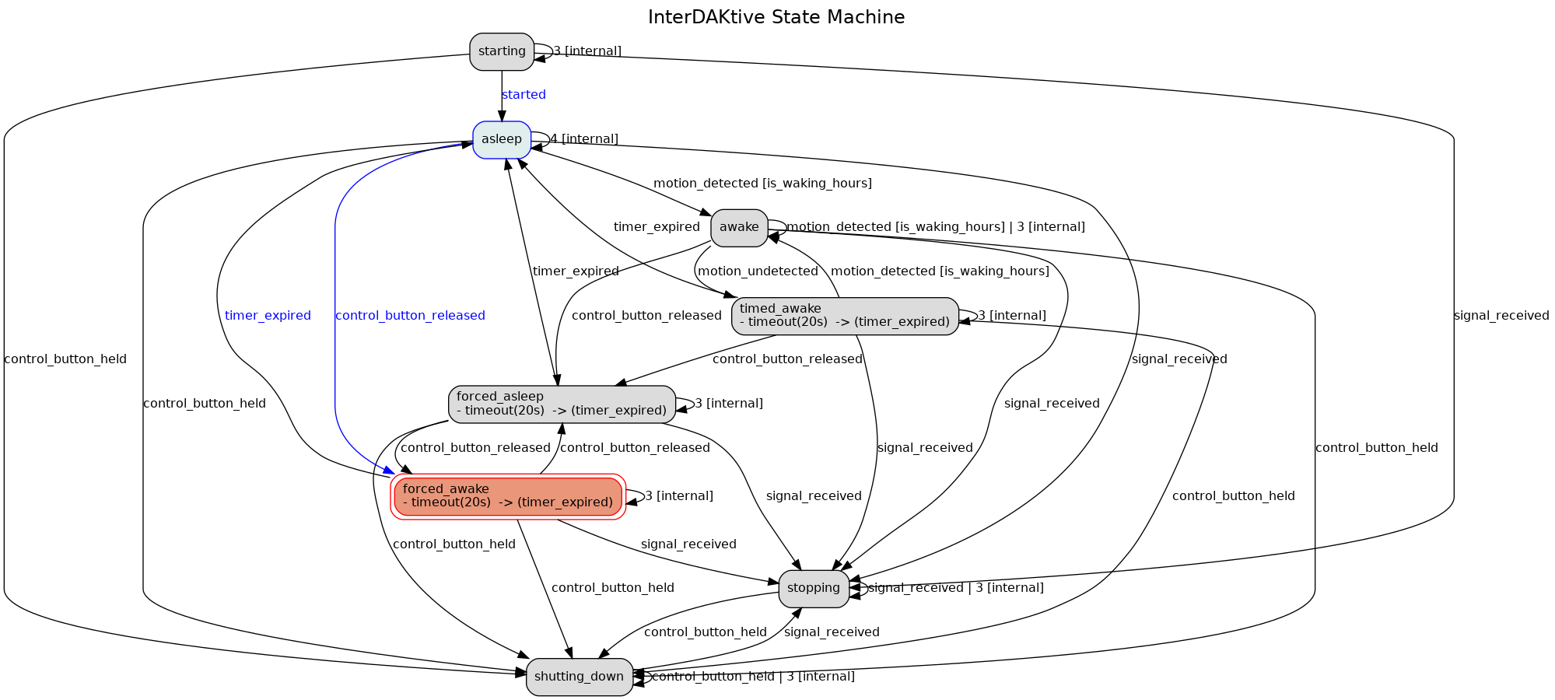
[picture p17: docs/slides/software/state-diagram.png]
State Diagram


===
### `transitions` for Finite State Machines

<pre class="stretch">
    <code
        class="language-python"
        data-src="https://raw.githubusercontent.com/robertbullen/dakboard/master/interdaktive/state_machine.py"
        data-trim
    >
    </code>
</pre>

===
### `typing` & `mypy` for Static Typing

<pre class="stretch">
    <code
        class="language-python"
        data-src="https://raw.githubusercontent.com/robertbullen/dakboard/master/interdaktive/display.py"
        data-trim
    >
    </code>
</pre>

===
### `watchdog`, `flask` & `flask-socketio` for a Status Webserver

<pre class="stretch">
    <code
        class="language-python"
        data-line-numbers="115-128"
        data-src="https://raw.githubusercontent.com/robertbullen/dakboard/master/interdaktive/webserver/__main__.py"
        data-trim
    >
    </code>
</pre>

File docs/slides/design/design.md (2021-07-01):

<!-- .slide: id="design-design" -->
# Design

===
<!-- .slide: id="design-templates" -->
## Existing Templates

- Existing templates are attractive but calendars are either sparse or have small text
- I challenged myself to create a custom design that was both attractive and dense with information

<div class="figures equisized">
    <figure>
        <p>DAKboard Template 1</p>
    </figure>
    <figure>
        <p>DAKboard Template 2</p>
    </figure>
    <figure>
        <p>DAKboard Template 3</p>
    </figure>
    <figure>
        <p>DAKboard Template 4</p>
    </figure>
</div>

===
<!-- .slide: id="design-font" -->
## Font

===
<!-- .slide: id="design-font-criteria" -->
### Font Selection Criteria

<style>
    #design-font-criteria .figures {
        font-size: smaller;
    }

    #design-font-criteria .figures img {
        height: auto;
        width: 220px;
    }

    #design-font-criteria .figures figcaption {
        font-size: smaller;
    }
</style>

<div class="figures">
    <figure class="fragment">
        <h4>Availability</h4>
        <p>
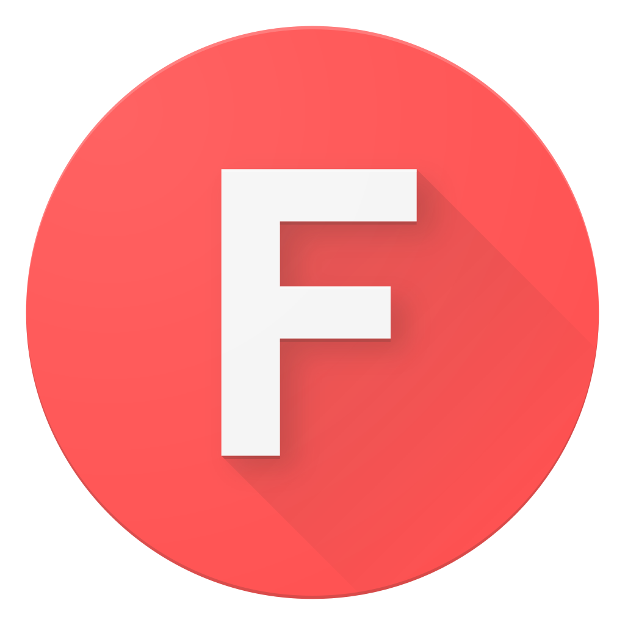
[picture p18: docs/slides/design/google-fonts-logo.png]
Google Fonts Logo
            
        </p>
        <figcaption>fonts.google.com</figcaption>
    </figure>
    <figure class="fragment">
        <h4>Features</h4>
        <p>
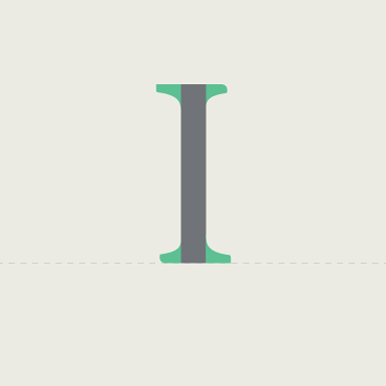
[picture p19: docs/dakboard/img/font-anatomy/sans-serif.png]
Sans-Serif
            
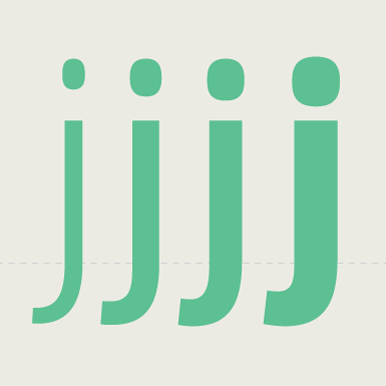
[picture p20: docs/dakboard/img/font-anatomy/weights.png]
Weight
            
        </p>
        <figcaption class="small">Sans serif; Normal & light weights</figcaption>
    </figure>
    <figure class="fragment">
        <h4>Numbers</h4>
        <p>
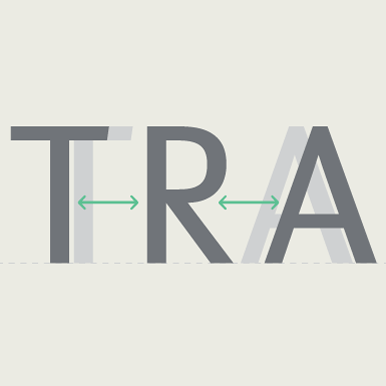
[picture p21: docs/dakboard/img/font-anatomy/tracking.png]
Tracking
            
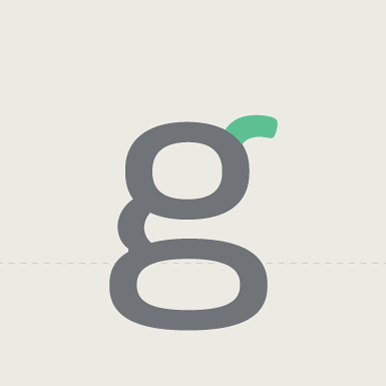
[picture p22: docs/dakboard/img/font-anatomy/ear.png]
Ear
            
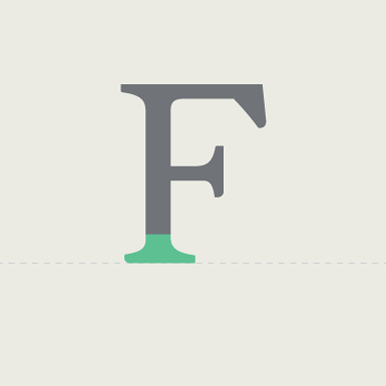
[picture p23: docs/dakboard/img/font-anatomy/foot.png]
Foot
            
        </p>
        <figcaption>Invariant tracking, <em>1</em> with an ear but no foot</figcaption>
    </figure>
    <figure class="fragment">
        <h4>Letter Forms</h4>
        <p>
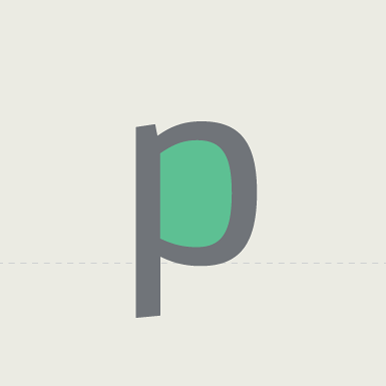
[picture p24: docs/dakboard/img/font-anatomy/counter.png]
Counter
            
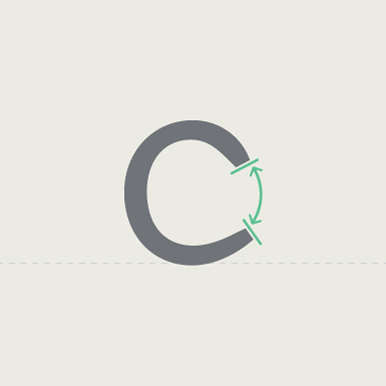
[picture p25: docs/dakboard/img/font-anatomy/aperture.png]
Aperture
            
            Bowl
        </p>
        <figcaption>Large counters & apertures; tall oval bowls</figcaption>
    </figure>
    <figure class="fragment">
        <h4>Lowercase</h4>
        <p>
            X-height
            Tiers
        </p>
        <figcaption>Tall x-height & two-tiered <em>a</em></figcaption>
    </figure>
    <figure class="fragment">
        <h4>Mark Shapes</h4>
        <p>
            Terminal
            Tittle
        </p>
        <figcaption>Angular terminals; circular <em>:</em> & tittles</figcaption>
    </figure>
</div>
<p>Graphics from <a href="https://www.fontsmith.com/blog/2016/06/29/the-a-z-of-typographic-terms">Fontsmith's <cite>The A-Z of Typographic Terms</cite></a>.</p>

===
<!-- .slide: id="design-font-candidates" -->
### Font Candidates

<style>
    @import url('https://fonts.googleapis.com/css2?family=Montserrat&display=swap');
    @import url('https://fonts.googleapis.com/css2?family=Open+Sans&display=swap');
    @import url('https://fonts.googleapis.com/css2?family=Oxygen&display=swap');
    @import url('https://fonts.googleapis.com/css2?family=Poppins&display=swap');
    @import url('https://fonts.googleapis.com/css2?family=PT+Sans&display=swap');
    @import url('https://fonts.googleapis.com/css2?family=Roboto&display=swap');
    @import url('https://fonts.googleapis.com/css2?family=Ubuntu&display=swap');

    #design-font-candidates > table > thead > tr > th:nth-child(3),
    #design-font-candidates > table > thead > tr > th:nth-child(4),
    #design-font-candidates > table > thead > tr > th:nth-child(5),
    #design-font-candidates > table > thead > tr > th:nth-child(6) {
        font-size: smaller;
        transform: rotate(-45deg);
        max-width: 42px;
        min-width: 42px;
        white-space: nowrap;
    }

    #design-font-candidates > table > tbody > tr > td:nth-child(2) {
        font-size: larger;
    }
    #design-font-candidates > table > tbody > tr > td:nth-child(1n+3) {
        font-size: smaller;
        vertical-align: middle;
    }

    #design-font-candidates > table > tbody > tr > td abbr {
        text-decoration: none;
    }

    #design-font-candidates > table > tbody > tr:nth-child(1) > td:nth-child(2) {
        font-family: 'Roboto';
    }

    #design-font-candidates > table > tbody > tr:nth-child(2) > td:nth-child(2) {
        font-family: 'Montserrat';
    }

    #design-font-candidates > table > tbody > tr:nth-child(3) > td:nth-child(2) {
        font-family: 'Open Sans';
    }

    #design-font-candidates > table > tbody > tr:nth-child(4) > td:nth-child(2) {
        font-family: 'Oxygen';
    }

    #design-font-candidates > table > tbody > tr:nth-child(5) > td:nth-child(2) {
        font-family: 'Poppins';
    }

    #design-font-candidates > table > tbody > tr:nth-child(6) > td:nth-child(2) {
        font-family: 'PT Sans';
    }

    #design-font-candidates > table > tbody > tr:nth-child(7) > td:nth-child(2) {
        font-family: 'Ubuntu';
    }

    #design-font-candidates > p {
        align-items: center;
        display: flex;
        justify-content: center;
        margin-top: 40px;
        font-size: smaller;
    }

    #design-font-candidates > p > * {
        margin: 0 1rem;
    }

    #design-font-candidates > p > a > * {
        vertical-align: middle;
    }

    #design-font-candidates > p > input {
        width: 25%;
    }
</style>

| Name | Example | Numbers | Letter Forms | Lowercase | Mark Shapes |
| --- | --- | :---: | :---: | :---: | :---: |
| Roboto (default) | 11:59 Sun aoce Illiterate Wx Jj rnm O0 | <abbr title="">🟢</abbr> | <abbr title="Narrow apertures">🔴</abbr> | <abbr title="Medium x-height">🟠</abbr> | <abbr title="">🟢</abbr> |
| Montserrat | 11:59 Sun aoce Illiterate Wx Jj rnm O0 | <abbr title="Variable tracking">🔴</abbr> | <abbr title="Medium apertures; circular bowls">🟠</abbr> | <abbr title="">🟢</abbr> | <abbr title="">🟢</abbr> |
| Open Sans | 11:59 Sun aoce Illiterate Wx Jj rnm O0 | <abbr title="">🟢</abbr> | <abbr title="">🟢</abbr> | <abbr title="">🟢</abbr> | <abbr title="">🟢</abbr> |
| Oxygen | 11:59 Sun aoce Illiterate Wx Jj rnm O0 | <abbr title="Variable tracking">🔴</abbr> | <abbr title="">🟢</abbr> | <abbr title="">🟢</abbr> | <abbr title="Square tittles & colon">🔴</abbr> |
| Poppins | 11:59 Sun aoce Illiterate Wx Jj rnm O0 | <abbr title="Variable tracking">🔴</abbr> | <abbr title="Narrow apertures; circular bowls">🔴</abbr> |  <abbr title="Single-tier a">🔴</abbr>  | <abbr title="">🟢</abbr> |
| PT Sans | 11:59 Sun aoce Illiterate Wx Jj rnm O0 | <abbr title="1 has a foot">🔴</abbr> | <abbr title="">🟢</abbr> | <abbr title="Medium x-height">🟠</abbr> | <abbr title="">🟢</abbr> |
| Ubuntu | 11:59 Sun aoce Illiterate Wx Jj rnm O0 | <abbr title="">🟢</abbr> | <abbr title="">🟢</abbr> | <abbr title="">🟢</abbr> | <abbr title="">🟢</abbr> |

<p>
    <label for="font-scale-range">Grover distance simulator:</label>
    <a href="#" id="font-scale-farther-link">
        <span>Far</span>
        Far
    </a>
    <input id="font-scale-range" max="1.0" min="0.1" step="0.1" type="range" value="1.0" />
    <a href="#" id="font-scale-nearer-link">
        Near
        <span>Near</span>
    </a>
</p>

===
<!-- .slide: id="design-background-and-colors" -->
## Background and Colors

===
<!-- .slide: class="columns layout" id="design-background" -->
### Background Image and Colors

- Column

    Background Image

- Column

    - Looked for an organic, daring background
    - Selected this one from [Unsplash's *Textures & Patterns*](https://unsplash.com/t/textures-patterns)
    - Analyzed its color palette using [Canva's *Color Palette Generator*](https://www.canva.com/colors/color-palette-generator/)

        Canva Palette Results

    - Chose <span style="color: #8C115C">Medium Violet Red (#8C115C)</span> as the starting point for foreground colors

===
<!-- .slide: class="columns layout" id="design-colors" -->
### Foreground Colors

- Column

    - Kept white as the default foreground text
    - Adopted family conventions for calendar colors&mdash;no legend or names required!
        - Pink for Emily <!-- .element style="color: #f755b7;" -->
        - Orange for Robert <!-- .element style="color: #ffb157;" -->
        - Blue for Brooke <!-- .element style="color: #5bc1f2;" -->
        - Green for Kerry <!-- .element style="color: #c9fd57;" -->
    - Used [paletton.com](https://paletton.com/#uid=758180kl1Wx1x+IcEXDsUWkWEVB) to generate a coherent color palette based off of <span style="color: #8C115C">Medium Violet Red</span>

- Column

    Paletton.com Colors

===
<!-- .slide: id="design-layout-and-css" -->
## Layout and CSS

===
<!-- .slide: id="design-layout-to-finished-product" -->
### Initial Layout to Finished Product

<style>
    #design-layout-to-finished-product img {
        height: 800px;
    }
</style>

<div class="figures equisized">
    <figure>
        <p>Layout Designer</p>
        <figcaption>Layout Designer</figcaption>
    </figure>
    <figure>
        <p>Raw Result</p>
        <figcaption>Raw Result</figcaption>
    </figure>
    <figure>
        <p>Customized with CSS</p>
        <figcaption>Customized with CSS</figcaption>
    </figure>
</figures>

===
<!-- .slide: id="design-influence" -->
### Was I Influenced?

<style>
    #design-influence img {
        height: 470px;
        object-fit: cover;
        object-position: 0 100% ;
        width: 784px;
    }
</style>

- After my design was finalized, I realized that it shared similarities with Apple CarPlay
    - Translucent tiles
    - Rounded corners
    - Drop shadows

<div class="figures equisized">
    <figure>
        <p>Apple CarPlay</p>
    </figure>
    <figure>
        <p>My Design</p>
    </figure>
</figures>

===
<!-- .slide: data-background-image="slides/design/family-guy-css.gif" data-background-position="center" data-background-size="contain" id="design-css" -->

===
### CSS Calculations and Viewport Units for Infinite Scalability

<pre class="stretch">
    <code
        class="language-css"
        data-line-numbers data-src="https://raw.githubusercontent.com/robertbullen/dakboard/master/css/purply-derply.css"
        data-trim>
    </code>
</pre>

===
### Yields A Consistent Appearance Across Resolutions

<div class="figures equisized">
    <figure>
        <p>Full HD</p>
        <figcaption>HD (720×1280)</figcaption>
    </figure>
    <figure>
        <p>Full HD</p>
        <figcaption>Full HD (1080×1920)</figcaption>
    </figure>
    <figure>
        <p>QHD</p>
        <figcaption>QHD (1440×2560)</figcaption>
    </figure>
    <figure>
        <p>Full HD</p>
        <figcaption>UHD/4K (2160×3840)</figcaption>
    </figure>
</figures>

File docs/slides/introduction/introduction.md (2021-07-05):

<!-- .slide: id="introduction-introduction" -->
# Introduction

===
<!-- .slide: id="introduction-inspiration" -->
## Inspiration

<style>
    @import url('https://fonts.googleapis.com/css2?family=Shadows+Into+Light+Two&display=swap');

    #introduction-inspiration blockquote {
        font-size: larger;
        font-style: normal;
        padding: 40px;
        width: 50%;
    }

    #introduction-inspiration blockquote .wife {
        color: pink;
        text-align: left;
        font-family: 'Shadows Into Light Two', cursive;
        font-size: 90%;
    }
    #introduction-inspiration blockquote .wife::before {
        content: 'Wife:';
        display: inline-block;
        margin-right: 0.5em;
    }

    #introduction-inspiration blockquote .me {
        color: lightblue;
        font-family: monospace;
        text-align: right;
    }
    #introduction-inspiration blockquote .me::before {
        content: 'Me:';
        display: inline-block;
        margin-right: 0.5em;
    }
</style>

> "My friend has a DAKboard and I think we need one." <!-- .element: class="wife" -->
>
> "A what?" <!-- .element: class="me" -->
>
> "..." <!-- .element: class="wife" -->
>
> "I'll look into it." <!-- .element: class="me" -->

===
<!-- .slide: id="introduction-dakboard" -->
### What Is a DAKboard?

DAKboard Shopping Site <!-- .element: style="max-height: 900px;" -->

===
<!-- markdownlint-disable no-trailing-punctuation -->
### But What Is DAKboard Really?
<!-- markdownlint-enable no-trailing-punctuation -->

<div class="figures equisized">
    <figure class="fragment">
        <p>
            DAKboard Console
        </p>
        <figcaption>Web console for configuring your dashboard content</figcaption>
    </figure>
    <figure class="fragment">
        <p>
            DAKboard Dashboard
        </p>
        <figcaption>Service that composes and delivers your dashboard as HTML</figcaption>
    </figure>
    <figure class="fragment">
        <p>
            DAKboard Device
        </p>
        <figcaption>Rendered by a Raspberry Pi running Chromium in kiosk mode</figcaption>
    </figure>
</div>

===
### DAKboard Supports DIY

<iframe class="stretch" data-src="https://blog.dakboard.com/diy-wall-display/"></iframe>

===
<!-- .slide: id="introduction-goals" -->
## DIY Goals

- Functional
- Aesthetic
- Personal/Professional

===
<!-- .slide: class="columns layout" -->
### Functional Goals

- Column

    Classroom Monthly Calendar

- Column

    - Display content
        - Date and time
        - Weather forecast
        - Consolidated family calendar
        - Photo roll
        - Countdown to the next important event
        - Local news headlines
    - **Control the display intelligently**
        - **Turn on only while viewing**
        - **Keep off during nighttime hours**
        - **Support push-button overriding of those rules**

===
<!-- .slide: class="columns layout" id="introduction-aesthetic-goals" -->
### Aesthetic Goals

<style>
    #no-sign {
        font-size: 500px;
        margin-top: -525px;
        opacity: 0.9;
        position: relative;
        top: -100px;
    }
</style>

- Column

    - Accommodate all the aforementioned content without feeling busy or cluttered
    - Fit into a home, not a business or commercial setting
    - Incorporate nature into the design motif
    - Achieve a high [wife acceptance factor](https://en.wikipedia.org/wiki/Wife_acceptance_factor)

- Column

    Example of Ugly Dashboard

    🚫<!-- .element: id="no-sign" -->

===
<!-- .slide: class="columns layout" -->
### Personal & Professional Goals

- Column

    Mario Power-ups

    <!-- markdownlint-disable heading-start-left no-trailing-punctuation -->
    #### Power Up!
    <!-- markdownlint-enable heading-start-left no-trailing-punctuation -->

- Column

    - Learn about programming electronics with Raspberry Pis
    - Delve deeper into the world of Python
    - Add an interesting project to my personal GitHub account...
    - ...With a nice presentation (you're lookin' at it!)
    - Reinforce my employer's decision to provide Personal Hack Days
    - Inspire others to embrace Personal Hack Days

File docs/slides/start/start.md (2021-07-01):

<!-- .slide: class="columns layout" id="start-title" -->

<style>
    #start-title h1 {
        margin-top: 25%;
    }

    #start-title img {
        border: solid rgba(255, 255, 255, 0.05) 20px;
        max-height: 1000px;
        width: auto;
    }
</style>

<!-- markdownlint-disable first-line-heading heading-start-left -->

- Column

    # Bullen Family Dashboard

- Column

    Dashboard Screenshot

<!-- markdownlint-enable first-line-heading heading-start-left -->

===
<!-- .slide: class="auto-width columns layout" id="toc" -->
## Table of Contents

<style>
    /* Prevent the lists within each column from centering themselves. */
    #toc > ul > li > ol {
        display: block;
        list-style: none;
        margin: 0;
    }

    /* Give a sense of hierarchy without using bullets and numbering. */
    #toc > ul > li > ol > li {
        text-transform: uppercase;
    }
    #toc > ul > li > ol > li > ul {
        font-size: 67%;
        text-transform: initial;
        list-style: none;
        margin: 0;
    }
    #toc > ul > li > ol > li > ul > li {
        margin: 1em 0;
    }
</style>

<!-- markdownlint-disable ol-prefix -->

- Column

    1. [Intro](#/introduction-introduction)
        - [Inspiration](#/introduction-inspiration)
        - [What is a DAKboard?](#/introduction-dakboard)
        - [Goals](#/introduction-goals)

- Column

    2. [Hardware](#/hardware-hardware)
        - [Prototype](#/hardware-prototype)
        - [Final Design](#/hardware-final-design)

- Column

    3. [Demos](#/demos-demos)
        - [Dashboard](#/demos-dashboard)
        - [Motion Detection](#/demos-motion-detection)

- Column

    1. [Design](#/design-design)
        - [Font](#/design-font)
        - [Background & Colors](#/design-background-and-colors)
        - [Layout & CSS](#/design-layout-and-css)

- Column
  
    5. [Software](#/software-software)
        - [Controlling Displays](#/software-controlling-displays)
        - [Python Packages](#/software-python-packages)

- Column

    6. [Conclusion](#/conclusion-conclusion)
        - [Comparisons](#/conclusion-comparisons)
        - [Learnings & Benefits](#/conclusion-learnings)
        - [Links](#/conclusion-links)

<!-- markdownlint-enable ol-prefix -->

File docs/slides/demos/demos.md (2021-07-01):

<!-- .slide: id="demos-demos" -->
# Demos

===
<!-- .slide: class="columns layout" id="demos-dashboard" -->

<style>
    #demos-dashboard h2 {
        margin-top: 25%;
    }

    #demos-dashboard img {
        border: solid rgba(255, 255, 255, 0.05) 20px;
        max-height: 1000px;
        width: auto;
    }
</style>

<!-- markdownlint-disable first-line-heading heading-start-left -->

- Column

    ## Dashboard

- Column

    Dashboard Screenshot

<!-- markdownlint-enable first-line-heading heading-start-left -->

===
<!-- .slide: id="demos-motion-detection" -->
## Motion Detection

===
<form
    class="stretch"
    data-fragment-index="1"
    id="status-url-form"
    style="display: grid; gap: 1rem; grid-template-columns: 2fr 1fr; grid-template-rows: auto 1fr; place-items: stretch;"
>
    <input
        id="status-url"
        name="status-url"
        placeholder="Enter the web address to an InterDAKtive webserver"
        style="font-size: x-large;"
        type="url"
    />
    <button
        style="font-size: x-large;"
        type="submit"
    >
        Load Site and Open Webcam
    </button>
    <iframe
        id="status-iframe"
        style="display: block; max-height: unset; max-width: unset;"
    >
    </iframe>
    <video
        autoplay="true"
        id="demo-webcam"
        style="align-self: start; max-height: unset; max-width: unset; transform: scaleX(-1);"
    >
    </video>
</form>

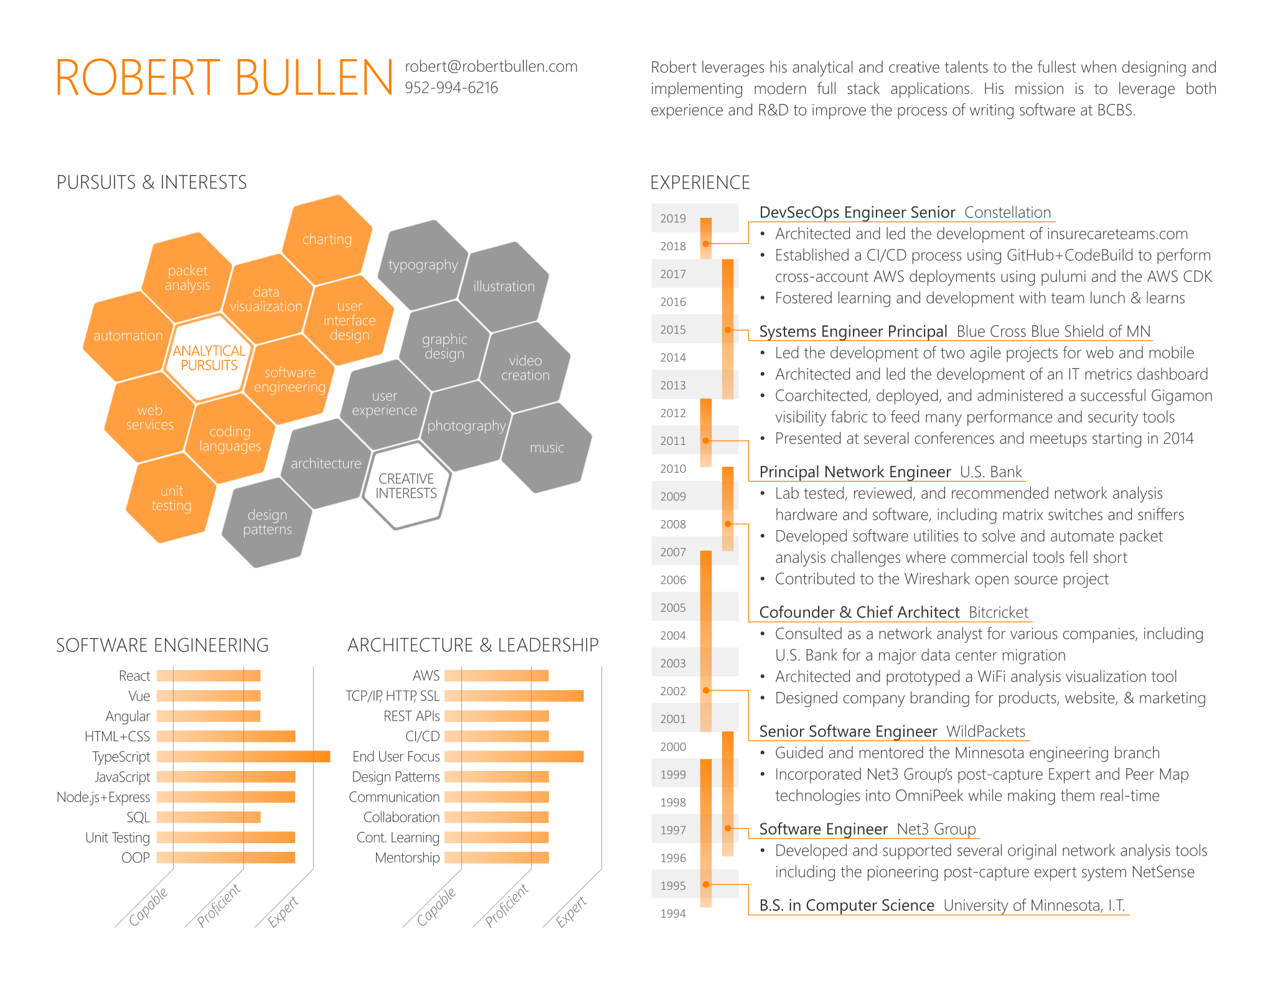
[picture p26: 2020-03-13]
docs/slides/design/greatest-hits/resume.png

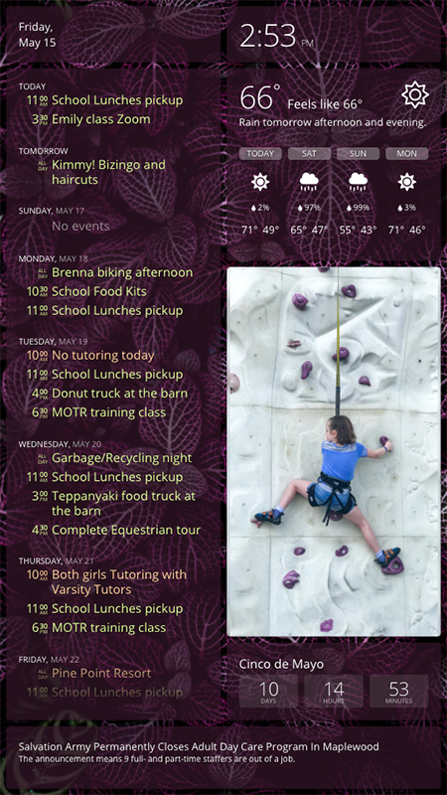
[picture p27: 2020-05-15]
docs/slides/design/design-customized.png

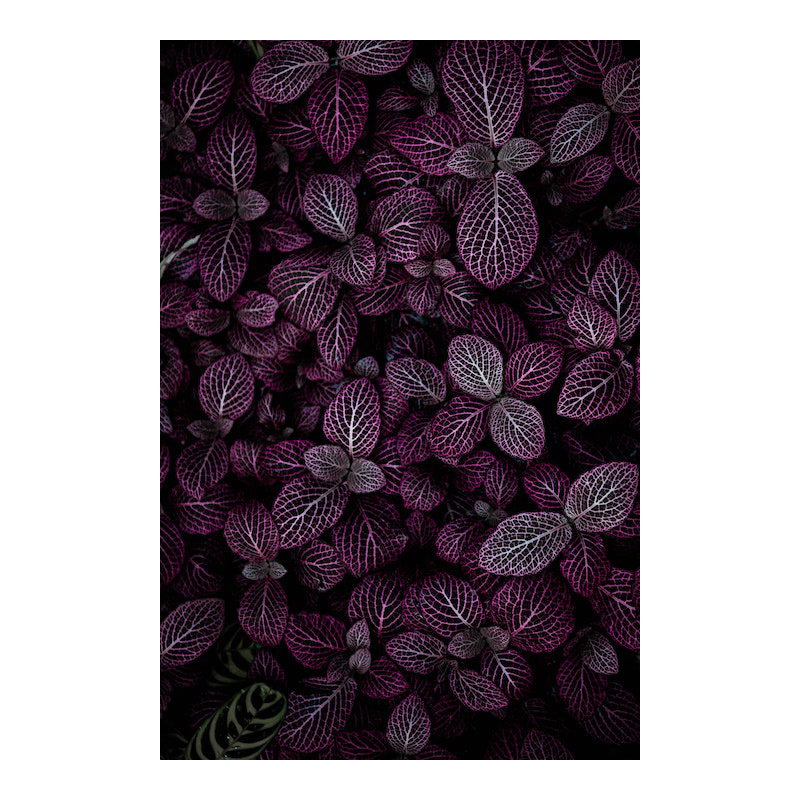
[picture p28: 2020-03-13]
docs/slides/design/purply-derply-background.jpg

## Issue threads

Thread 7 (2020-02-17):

Motion LED doesn't turn off when in the asleep state

robertbullen, 2020-02-17:

Closed 2020-02-17.

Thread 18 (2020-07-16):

Make presentation improvements

robertbullen, 2020-07-16:
"Delve _deeper_ into the world of Python"
"Reinforce management's decision to _provide this opportunity_"
"A monitor stand ~~on~~ was chosen over wall mounting"

Closed 2020-07-20.

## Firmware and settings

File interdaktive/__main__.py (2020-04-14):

import logging
import logging.handlers
import re
import signal
import sys
import threading
import types
from typing import List, Optional, Pattern, Type

from interdaktive.config import Config
from interdaktive.hardware import Hardware
from interdaktive.state_machine import StateMachine, Transitions

if __name__ == '__main__':
    # Load up the configuration from command line arguments.
    config: Config = Config.from_args()

    # Configure logging to write to rotating files.
    handlers: Optional[List[logging.Handler]] = None
    if config.log_file_path is not None:
        handlers = [logging.handlers.RotatingFileHandler(
            filename=config.log_file_path,
            maxBytes=int(16 * 2**10),
            backupCount=3,
        )]
    logging.basicConfig(
        format='%(asctime)s\t%(levelname)s\t%(name)s\t%(message)s',
        handlers=handlers,
        level=logging.DEBUG,
    )

    # Filter out a couple unwanted log messages from _transitions_.
    executed_save_state_diagram: Pattern[str] = re.compile(
        r'Executed machine finalize callback \'<function StateMachine\.__init__\.<locals>\.handle_finalize_event at 0x[0-9a-fA-F]+>\'.$'
    )
    returning_graph_model: Pattern[str] = re.compile(
        r'^Returning graph of the first model. In future releases, this method will return a combined graph of all models.$'
    )

    def filter(record: logging.LogRecord) -> bool:
        global executed_save_state_diagram
        global returning_graph_model

        return (
            executed_save_state_diagram.match(record.getMessage()) is None
            and returning_graph_model.match(record.getMessage()) is None
        )

    logging.getLogger('transitions.core').addFilter(filter)
    logging.getLogger('transitions.extensions.diagrams').addFilter(filter)

    # Log any unhandled exceptions.
    logger = logging.getLogger(__name__)

    def handle_unhandled_exception(
        exc_type: Type[BaseException],
        exc_value: BaseException,
        exc_traceback: types.TracebackType,
    ) -> None:
        global logger

        if issubclass(exc_type, KeyboardInterrupt):
            # Call the default hook.
            sys.__excepthook__(exc_type, exc_value, exc_traceback)
            return

        logger.exception("Unhandled exception", exc_info=(exc_type, exc_value, exc_traceback))

    sys.excepthook = handle_unhandled_exception

    # Instantiate hardware objects.
    hardware = Hardware(config)

    # Create the state machine.
    state_machine = StateMachine(config, hardware)

    # Wire the state machine up to external events.
    def handle_signal(signal_number: signal.Signals, frame: types.FrameType) -> None:
        state_machine[Transitions.signal_received](signal_number=signal_number, frame=frame)

    signal.signal(signal.SIGINT, handle_signal)
    signal.signal(signal.SIGTERM, handle_signal)

    hardware.motion_sensor.when_motion = state_machine[Transitions.motion_detected]
    hardware.motion_sensor.when_no_motion = state_machine[Transitions.motion_undetected]

    if hardware.control_button:
        hardware.control_button.when_released = state_machine[Transitions.control_button_released]
        hardware.control_button.when_held = state_machine[Transitions.control_button_held]

    # Transition the state machine to operational mode and run until signalled to quit.
    state_machine[Transitions.started]()
    signal.pause()

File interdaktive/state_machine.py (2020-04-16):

import collections
import functools
import logging
import os
import signal
import subprocess
import time
from dataclasses import astuple, dataclass, fields
from typing import (Any, Callable, Dict, Iterator, List, Optional, Tuple, Type,
                    Union, cast)

import gpiozero
from transitions.extensions import GraphMachine
from transitions.extensions.states import Timeout, add_state_features

from interdaktive.config import Config
from interdaktive.hardware import BlinkRate, Hardware


@dataclass(frozen=True)
class States:
    starting: str = 'starting'

    stopping: str = 'stopping'
    shutting_down: str = 'shutting_down'

    awake: str = 'awake'
    timed_awake: str = 'timed_awake'
    forced_awake: str = 'forced_awake'

    forced_asleep: str = 'forced_asleep'
    asleep: str = 'asleep'

    def __iter__(self) -> Iterator[str]:
        return iter(astuple(self))


@dataclass(frozen=True)
class Transitions:
    started: str = 'started'

    control_button_held: str = 'control_button_held'
    control_button_released: str = 'control_button_released'

    motion_detected: str = 'motion_detected'
    motion_undetected: str = 'motion_undetected'

    timer_expired: str = 'timer_expired'

    signal_received: str = 'signal_received'

    def __iter__(self) -> Iterator[str]:
        return iter(astuple(self))


class StateMachine(object):
    config: Config
    hardware: Hardware
    machine: GraphMachine
    __are_edge_labels_shortened: bool = False

    def __init__(self, config: Config, hardware: Hardware) -> None:
        self.config = config
        self.hardware = hardware

        # A few states require timeouts, so add the feature to them while converting all the
        # `States` to a list.
        states_with_features: List[Union[Dict[str, Union[int, str]], str]] = []
        for state in States():
            if state == States.forced_asleep or state == States.forced_awake or state == States.timed_awake:
                states_with_features.append({
                    'name': state,
                    'timeout': self.config.timer_seconds,
                    'on_timeout': Transitions.timer_expired
                })
            else:
                states_with_features.append(state)

        # Instantiate a GraphMachine.
        machine_class_with_features = add_state_features(Timeout)(GraphMachine)

        def handle_finalize_event(*args: Any, **kwargs: Any) -> None:
            logger = logging.getLogger(__name__).debug('----------')
            self.save_state_diagram()

        self.machine = machine_class_with_features(
            model=self,
            states=states_with_features,
            initial=States.starting,
            auto_transitions=False,
            show_conditions=True,
            show_state_attributes=True,
            title='InterDAKtive State Machine',
            finalize_event=handle_finalize_event,
        )

        # Tweak the state diagram layout to yield a more readable result. Start with changing the
        # font for all elements. DejaVu is the default sans-serif font on Raspbian at the time of
        # this writing, but to use the condensed variant a generic name cannot be given; i.e.
        # 'sans-serif condensed' doesn't work. Also orient the diagram top-to-bottom.
        self.machine.machine_attributes['fontname'] = 'DejaVu Sans Condensed'
        self.machine.machine_attributes['fontsize'] = '18.0'

        self.machine.style_attributes['edge']['default']['fontname'] = 'DejaVu Sans Condensed'
        self.machine.style_attributes['edge']['default']['fontsize'] = '12.0'
        self.machine.style_attributes['edge']['previous']['fontcolor'] = 'blue'

        self.machine.style_attributes['node']['default']['fillcolor'] = 'gainsboro'
        self.machine.style_attributes['node']['default']['fontname'] = 'DejaVu Sans Condensed'
        self.machine.style_attributes['node']['default']['fontsize'] = '12.0'

        self.machine.machine_attributes['labelloc'] = 'top'
        self.machine.machine_attributes['rankdir'] = 'TB'

        # Add transitions for process control: starting, stopping, and shutting_down.
        self.machine.add_transition(Transitions.started, States.starting, States.asleep,
                                    prepare=self.hardware.running_led_on)

        self.machine.add_transition(Transitions.signal_received, '*', States.stopping,
                                    after=[
                                        self.hardware.motion_led_off,
                                        self.hardware.display_off,
                                        self.hardware.running_led_off,
                                        self.quit,
                                    ])

        self.machine.add_transition(Transitions.control_button_held, '*', States.shutting_down,
                                    after=self.shutdown)

        # Add transitions for motion (un)detected.
        self.machine.add_transition(Transitions.motion_detected, [States.asleep, States.timed_awake, States.awake], States.awake,
                                    prepare=self.hardware.motion_led_on,
                                    # A string is not required here, but it won't show up on a diagram otherwise.
                                    conditions=self.is_waking_hours.__name__)
        self.machine.add_transition(Transitions.motion_detected, '*', None)

        self.machine.add_transition(Transitions.motion_undetected, States.awake, States.timed_awake,
                                    prepare=self.hardware.motion_led_off)
        self.machine.add_transition(Transitions.motion_undetected, States.asleep, None,
                                    prepare=self.hardware.motion_led_off)
        self.machine.add_transition(Transitions.motion_undetected, '*', None)

        self.machine.add_transition(Transitions.timer_expired, States.timed_awake, States.asleep)

        # Add transitions into and out of the forced states.
        self.machine.add_transition(Transitions.control_button_released, [States.asleep, States.forced_asleep], States.forced_awake)
        self.machine.add_transition(Transitions.control_button_released, [States.forced_awake, States.timed_awake, States.awake], States.forced_asleep)
        self.machine.add_transition(Transitions.control_button_released, '*', None)

        self.machine.add_transition(Transitions.timer_expired, [States.forced_asleep, States.forced_awake], States.asleep)

        # Save an initial diagram.
        self.save_state_diagram()

    def __getitem__(self, key: str) -> Callable[..., None]:
        return cast(Callable[..., None], getattr(self, getattr(Transitions, key)))

    # Methods

    def save_state_diagram(self) -> None:
        if self.config.state_diagram_file_path is not None:
            graph = self.machine.get_graph()
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

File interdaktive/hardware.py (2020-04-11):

from enum import Enum
from typing import Any, Callable, Optional, Tuple

from gpiozero import LED, Button, MotionSensor

from interdaktive.config import Config
from interdaktive.display import Display


class BlinkRate(Enum):
    SLOW = 1.5
    FAST = 0.33


def optional_led_blink(led: Optional[LED], rate: BlinkRate) -> None:
    if led is not None:
        led.blink(rate.value, rate.value, background=True)


def optional_led_off(led: Optional[LED]) -> None:
    if led is not None:
        led.off()


def optional_led_on(led: Optional[LED]) -> None:
    if led is not None:
        led.on()


class Hardware(object):
    control_button: Optional[Button]
    display: Display
    motion_led: Optional[LED]
    motion_sensor: MotionSensor
    running_led: Optional[LED]

    def __init__(self, config: Config):
        self.display = Display.create(config.display_type)
        self.motion_sensor = MotionSensor(config.motion_sensor_pin)

        if config.control_button_pin is not None:
            self.control_button = Button(config.control_button_pin, hold_time=5)

        if config.motion_led_pin is not None:
            self.motion_led = LED(config.motion_led_pin)

        if config.running_led_pin is not None:
            self.running_led = LED(config.running_led_pin)

    def display_off(self, *args: Any, **kwargs: Any) -> 'Hardware':
        self.display.off()
        return self

    def display_on(self, *args: Any, **kwargs: Any) -> 'Hardware':
        self.display.on()
        return self

    def motion_led_blink(self, rate: BlinkRate, *args: Any, **kwargs: Any) -> 'Hardware':
        optional_led_blink(self.motion_led, rate)
        return self

    def motion_led_off(self, *args: Any, **kwargs: Any) -> 'Hardware':
        optional_led_off(self.motion_led)
        return self

    def motion_led_on(self, *args: Any, **kwargs: Any) -> 'Hardware':
        optional_led_on(self.motion_led)
        return self

    def running_led_off(self, *args: Any, **kwargs: Any) -> 'Hardware':
        optional_led_off(self.running_led)
        return self

    def running_led_on(self, *args: Any, **kwargs: Any) -> 'Hardware':
        optional_led_on(self.running_led)
        return self

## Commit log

2020-02-04 added some design source files
    [dakboard.fzz]
2020-02-04 added a control button
    [dakboard.fzz]
2020-02-05 improved layout of Fritzing drawing
    [dakboard.fzz]
2020-02-07 made a couple small fixes
2020-02-12 added more prep material
2020-02-13 explicitly turned off devices when stopping
2020-02-14 multiple quality improvements: - improved some identifier names and readability - added mypy config file - increased mypy strictness and corrected for it - printed the signal received before quiting
    [__main__.py, config.py, display.py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]
2020-02-14 added `--skip-updates` switch to start.sh script
2020-02-14 - made formatting work with IDE - silenced mypy errors
    [state_machine.py]
2020-02-17 added raspberry pi 3 image #1
2020-02-17 Fixed motion LED not turning off when asleep (closes #7)
    [state_machine.py]
2020-03-13 - switched font to Open Sans - tweaked figures layout - added interactive font scorecard
2020-04-08 fixed rotating log file size
    [__main__.py]
2020-04-11 - filtered out unwanted log messages - changed logger names from `__package__` to `__name__`
2020-04-11 gave `forced_awake` and `forced_asleep` states different LED blink rates
2020-04-13 improved commentary about socketio async mode
2020-04-13 shortened state diagram edge labels (closes #9)
    [state_machine.py]
2020-04-15 switched over some absolute sizings to relative units (#12)
2020-05-15 - improved button CSS - improved grover distance simulator
2021-05-25 Upgrade client socket.io
